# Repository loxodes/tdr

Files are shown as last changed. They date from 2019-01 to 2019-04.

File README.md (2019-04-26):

# tdr
Prototype time domain reflectometer/sampling oscilloscope.
90 gigasamples/second equivalent time sampling with an actual sampling rate of 5 kilosamples/second.

The input bandwidth is TBD, maybe 8 GHz?

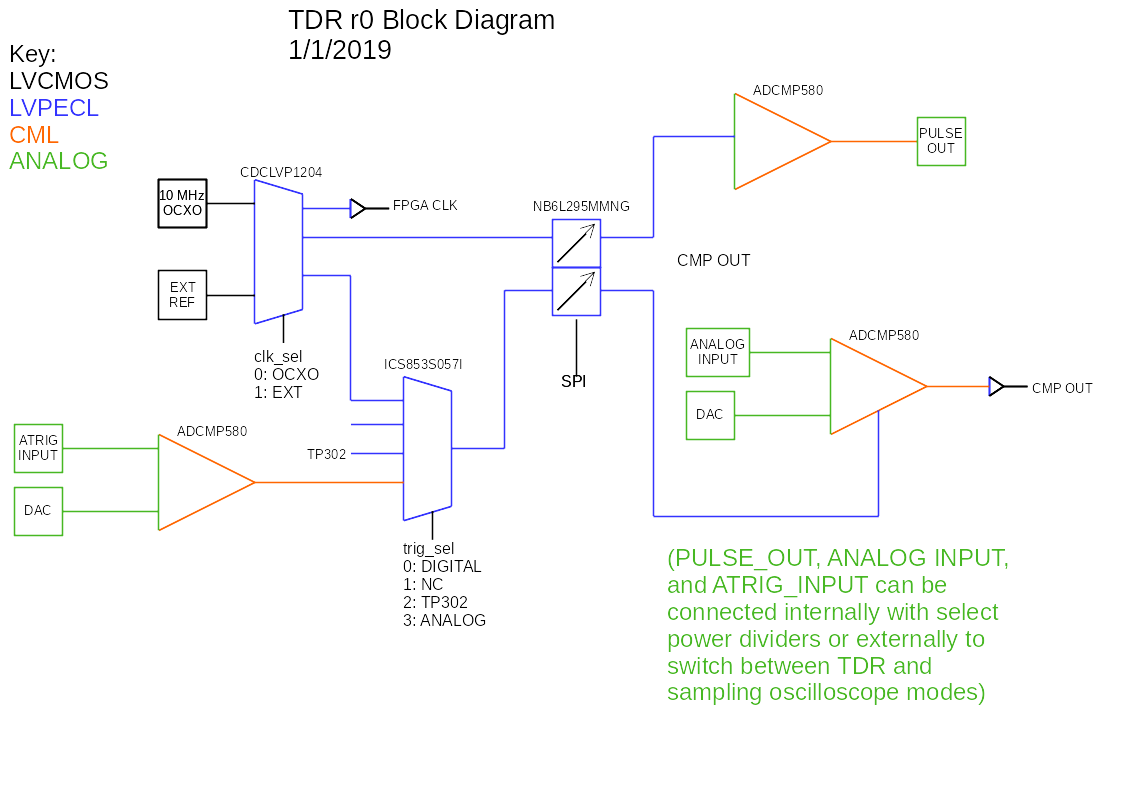
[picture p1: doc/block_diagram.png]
r0 block diagram

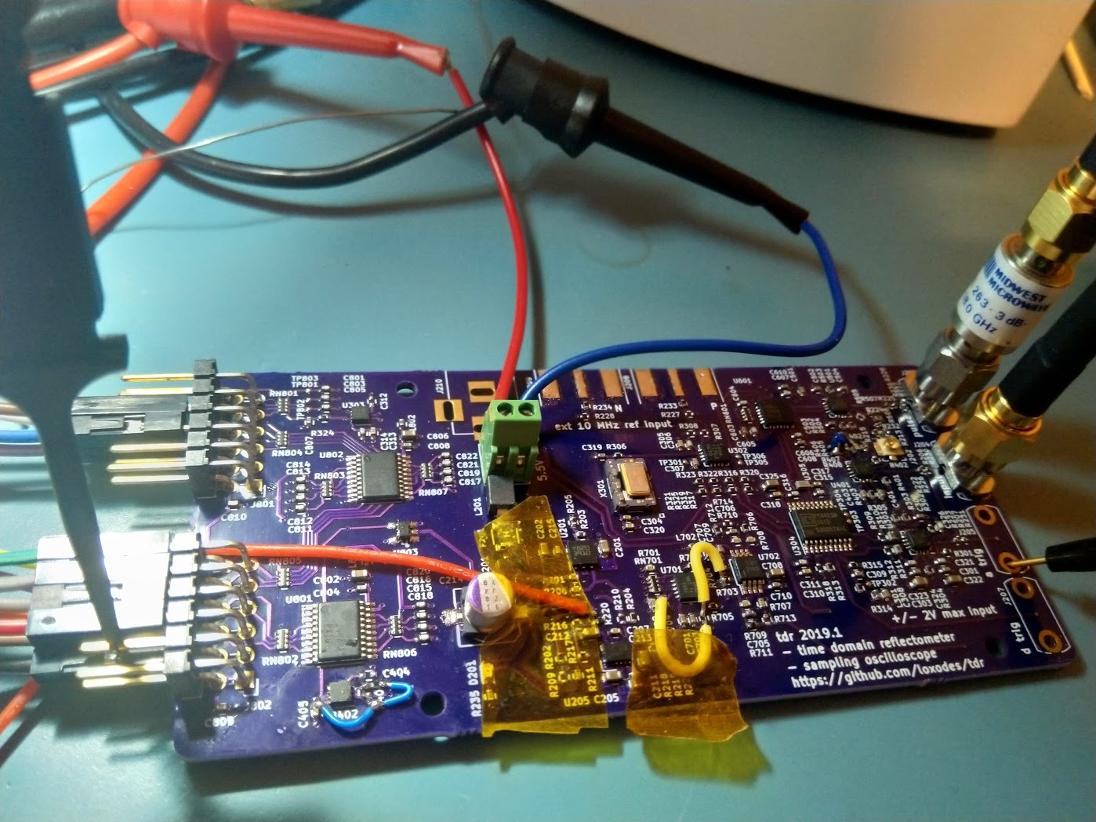
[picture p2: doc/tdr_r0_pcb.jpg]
r0 pcb


Following is sampling the falling edge of the TDR pulse, impedance of a BNC tee, and a 1.2 GHz sine wave with analog triggering.

r0 sweep
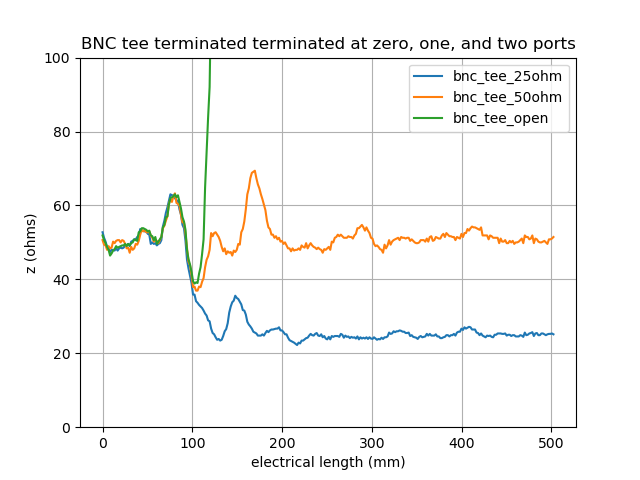
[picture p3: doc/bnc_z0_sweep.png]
r0 sweep

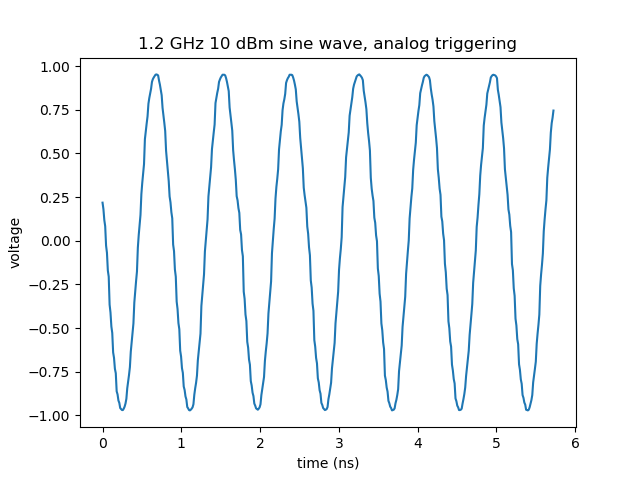
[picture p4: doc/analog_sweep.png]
r0 sweep


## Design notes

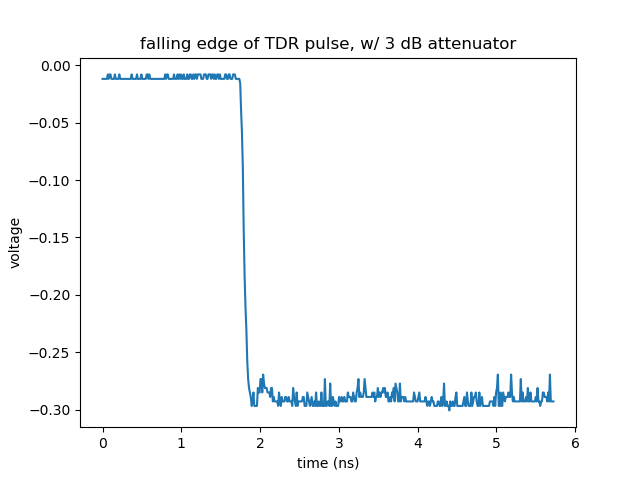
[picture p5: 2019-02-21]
doc/first_sweep.png

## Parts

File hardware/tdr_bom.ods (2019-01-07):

TDR R0 BOM
 | Item | Qty | Value | DigiKey PN | LibPart | Footprint | Reference(s)
 | 2 | 3 | 1 uF | 1276-1445-1-ND | Device:C_Small | Capacitors_SMD:C_0402 | C207, C701, C702
 | 3 | 1 | 10 uF | 490-10990-1-ND | Device:C_Small | Capacitors_SMD:C_0603 | C211
 | 4 | 12 | 4.7 uF | 1276-1784-1-ND | Device:C_Small | Capacitors_SMD:C_0603 | C212, C213, C201, C202, C205, C322, C324, C325, C406, C601, C707, C708,
 | 5 | 1 | 100 uF | P16482CT-ND | Device:CP1_Small | Capacitors_SMD:c_elec_6.3x5.8 | C214
 | 6 | 10 | 100 nF | 1292-1366-1-ND | Device:C_Small | Capacitors_SMD:C_0402 | C215, C305, C307, C310, C313, C317, C318, C320, C809, C810
 | 7 | 26 | 10 nF | 1276-1028-1-ND | Device:C_Small | Capacitors_SMD:C_0402 | C301, C302, C303, C304, C308, C309, C401, C402, C403, C405, C501, C502, C503, C504, C602, C603, C608, C610, C611, C613, C703, C704, C709, C710, C804, C808
 | 8 | 14 | 100 pF | 311-1024-1-ND | Device:C_Small | Capacitors_SMD:C_0402 | C306, C311, C314, C315, C316, C321, C323, C326, C604, C605, C606, C607, C609, C612
 | 9 | 2 | DNP | - | Device:C_Small | Capacitors_SMD:C_0402 | C312, C404
 | 10 | 4 | 10 pF | 1276-1139-1-ND | Device:C_Small | Capacitors_SMD:C_0402 | C319, C705, C706, C807
 | 11 | 4 | DNP | - | Device:C_Small | Capacitors_SMD:C_0603 | C802, C806
 | 12 | 15 | 33 pF | 311-1020-1-ND | Device:C_Small | Capacitors_SMD:C_0402 | C801, C803, C805, C811, C812, C813, C814, C815, C816, C817, C818, C819, C820, C821, C822
 | 13 | 1 | RED | 732-4978-1-ND | Device:LED | LEDs:LED_0603 | D201
 | 14 | 1 | Polyfuse_Small | F3371CT-ND | Device:Polyfuse_Small | Resistors_SMD:R_1210 | F201
 | 15 | 4 | MountingHole | - | Mechanical:MountingHole | Mounting_Holes:MountingHole_2-5mm | H201, H202, H203, H204
 | 16 | 1 | Conn_02x01 | A98333-ND | Connector_Generic:Conn_02x01 | Terminal_Blocks:TerminalBlock_Pheonix_MPT-2.54mm_2pol | J201
 | 17 | 1 | Conn_Coaxial | WM5587CT-ND | Connector:Conn_Coaxial | vna_footprints:734120110_ufl_umc | J202
 | 18 | 4 | Conn_Coaxial | SF2921-61345-2S-ND | Connector:Conn_Coaxial | vna_footprints:SF2921-61345 | J203, J204, J205, J207
 | 19 | 2 | Conn_Coaxial | WM5534-ND | Connector:Conn_Coaxial | vna_footprints:732511150_sma_thin_twopin | J208, J209
 | 20 | 1 | Barrel_Jack_Switch | - | Connector:Barrel_Jack_Switch | vna_footprints:BARREL_JACK | J210
 | 21 | 2 | Conn_02x06_Counter_Clockwise | A34346-06-ND | Connector_Generic:Conn_02x06_Counter_Clockwise | Pin_Headers:Pin_Header_Angled_2x06 | J801, J802
 | 22 | 1 | L_Small | 240-2435-1-ND | Device:L_Small | Resistors_SMD:R_1210 | L201
 | 23 | 5 | L_Small | 490-16507-1-ND | Device:L_Small | Resistors_SMD:R_0402 | L301, L701, L702, L801, L802
 | 24 | 1 | SI2369DS | SI2369DS-T1-GE3CT-ND | Device:Q_PMOS_GSD | TO_SOT_Packages_SMD:SOT-23 | Q201
 | 25 | 10 | 10k | RR05P10.0KDCT-ND | Device:R_Small | Resistors_SMD:R_0402 | R201, R208, R211, R235, R701, R707, R708, R709, R710, R712
 | 26 | 20 | JMP | 311-0.0JRCT-ND | Device:R_Small | Resistors_SMD:R_0402 | R202, R204, R227, R228, R233, R234, R301, R305, R324, R401, R405, R406, R407, R408, R502, R711, R220, R221, R306, R702
 | 30 | 2 | 1M | 311-1.00MLRCT-ND | Device:R_Small | Resistors_SMD:R_0402 | R216, R219
 | 31 | 2 | 332k | 311-332KLRCT-ND | Device:R_Small | Resistors_SMD:R_0402 | R217, R218
 | 33 | 7 | JMP | 311-0.0NCT-ND | Device:R_Small | Resistors_SMD:R_0201 | R222, R223, R229, R230, R231, R506, R507,
 | 34 | 3 | 50 | FC0402-50BWCT-ND | Device:R_Small | Resistors_SMD:R_0402 | R224, R309, R311
 | 35 | 8 | 1k | YAG1234CT-ND | Device:R_Small | Resistors_SMD:R_0402 | R303, R304, R313, R314, R315, R403, R503, R504
 | 36 | 4 | 84 | ERA-2AEB86R6X | Device:R_Small | Resistors_SMD:R_0402 | R316, R317, R322, R323
 | 37 | 4 | 125 | YAG4336CT-ND | Device:R_Small | Resistors_SMD:R_0402 | R319, R320, R321, R325
 | 38 | 1 | 100 | 311-2216-1-ND | Device:R_Small | Resistors_SMD:R_0402 | R404
 | 39 | 2 | 68 | 311-68UCT-ND | Device:R_Small | Resistors_SMD:R_0402 | R601, R602
 | 40 | 4 | 13k | YAG3274CT-ND | Device:R_Small | Resistors_SMD:R_0402 | R703, R704, R705, R706
 | 41 | 9 | 22 | Y7220CT-ND | Device:R_Pack04 | Resistors_SMD:R_Array_Convex_4x0402 | RN601, RN701, RN801, RN802, RN803, RN804, RN805, RN806, RN807
 | 42 | 1 | LD39100PU33R | 497-11013-1-ND | ld39100:LD39100 | Housings_DFN_QFN:DFN-6-1EP_3x3mm_Pitch0.95mm | U201
 | 43 | 1 | LM27762 | 296-47331-1-ND | lm27762:LM27762 | vna_footprints:WSON-12-1EP_3x2mm_Pitch0.5mm | U205
 | 45 | 1 | CDCLVP1204 | 296-41231-1-ND | tdr-rescue:CDCLVP1204-synth_lib-tdr-rescue | Housings_DFN_QFN:UQFN-16-1EP_3x3mm_Pitch0.5mm | U302
 | 47 | 1 | ICS853S057I | 800-2923-5-ND | tdr-rescue:ICS853S057I-tdr | Housings_SSOP:TSSOP-20_4.4x6.5mm_Pitch0.65mm | U304
 | 48 | 1 | X0060L5050AHF | Mouser X0060L5050AHF | synth_lib:X0060L5050AHF | synth_footprints:X0060L5050AHF | U305
 | 49 | 3 | ADCMP580 | ADCMP580BCPZ-WP-ND | tdr-rescue:ADCMP580-synth_lib-tdr-rescue | Housings_DFN_QFN:QFN-16-1EP_3x3mm_Pitch0.5mm | U301, U401, U501
 | 50 | 2 | SY89321L | 576-2954-1-ND | tdr-rescue:SY89321L-synth_lib-tdr-rescue | vna_footprints:DFN-8-1EP_2x2mm_Pitch0.5mm | U402, U303
 | 51 | 1 | NB6L295MMNG | NB6L295MMNGOS-ND | tdr-rescue:NB6L295MMNG-synth_lib-tdr-rescue | Housings_DFN_QFN:QFN-24-1EP_4x4mm_Pitch0.5mm | U601
 | 52 | 1 | DAC7563SDSCR | 296-29025-1-ND | synth_lib:DAC7563SDSCR | Housings_DFN_QFN:DFN-10-1EP_3x3mm_Pitch0.5mm | U701
 | 53 | 1 | OPA2140 | 296-46321-1-ND | Device:Opamp_Dual_Generic | Housings_SSOP:MSOP-8_3x3mm_Pitch0.65mm | U702
 | 54 | 2 | 74HC244 | MC74HC244ADTR2G | 74xx:74HC244 | Housings_SSOP:TSSOP-20_4.4x6.5mm_Pitch0.65mm | U801, U802
 | 55 | 1 | 74xx1G14 | 1727-3262-1-ND | 74xx1g14:74xx1G14 | TO_SOT_Packages_SMD:SOT-23-5 | U803
 | 56 | 1 | DV75D-010.0M | CW743CT-ND | tdr-rescue:DV75D_TCXO-synth_lib-tdr-rescue | vna_footprints:DV75D | X301

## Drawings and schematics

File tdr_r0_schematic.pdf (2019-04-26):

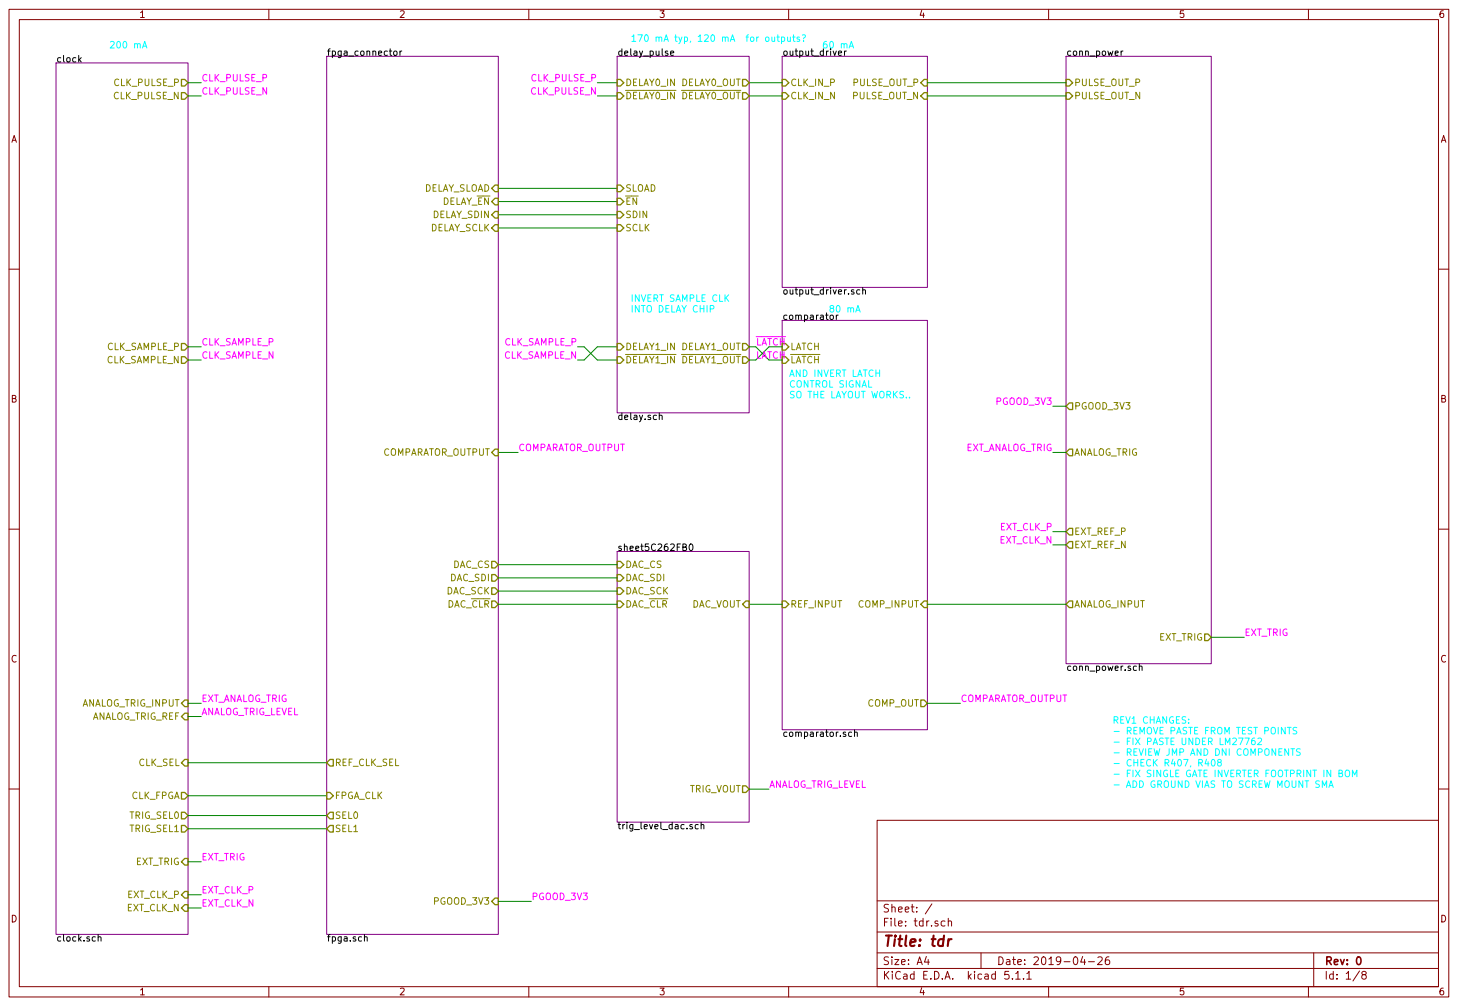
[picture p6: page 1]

CONTROL SIGNAL SO THE LAYOUT WORKS.. LATCH
LATCH

REV1 CHANGES: - REMOVE PASTE FROM TEST POINTS

- FIX PASTE UNDER LM27762
- REVIEW JMP AND DNI COMPONENTS
- CHECK R407, R408
- FIX SINGLE GATE INVERTER FOOTPRINT IN BOM
- ADD GROUND VIAS TO SCREW MOUNT SMA

Id: 1/8 Title: tdr File: tdr.sch Sheet: /

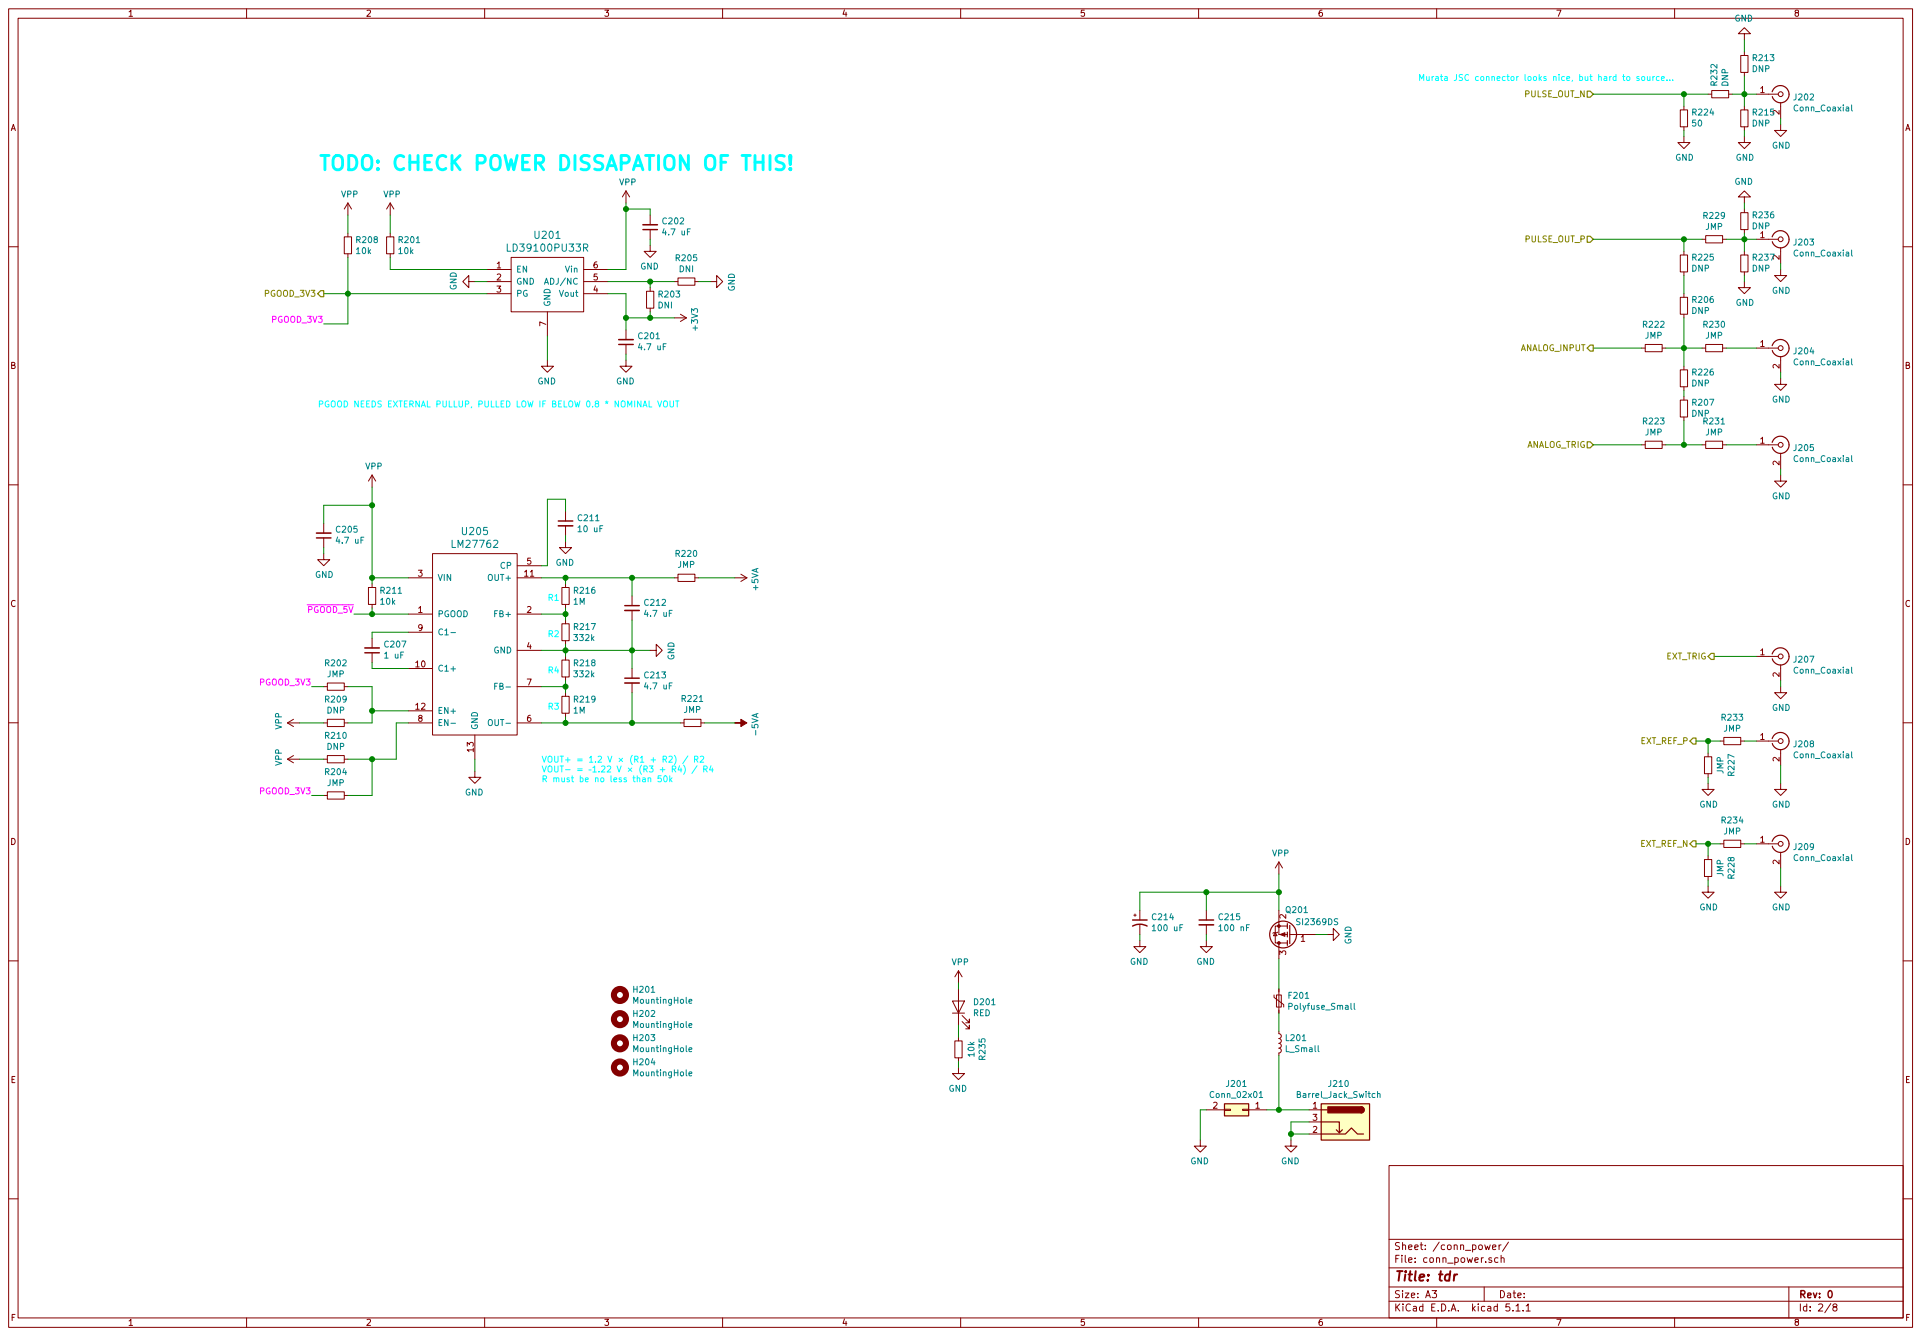
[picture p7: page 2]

Murata JSC connector looks nice, but hard to source...

PGOOD_3V3 PGOOD NEEDS EXTERNAL PULLUP, PULLED LOW IF BELOW 0.8 * NOMINAL VOUT TODO: CHECK POWER DISSAPATION OF THIS!
10k VPP
PGOOD_3V3 R204

VOUT- = 1.22 V × (R3 + R4) / R4 R must be no less than 50k R1 R2 R4 R3

H201 MountingHole H202 MountingHole H203 MountingHole H204 MountingHole

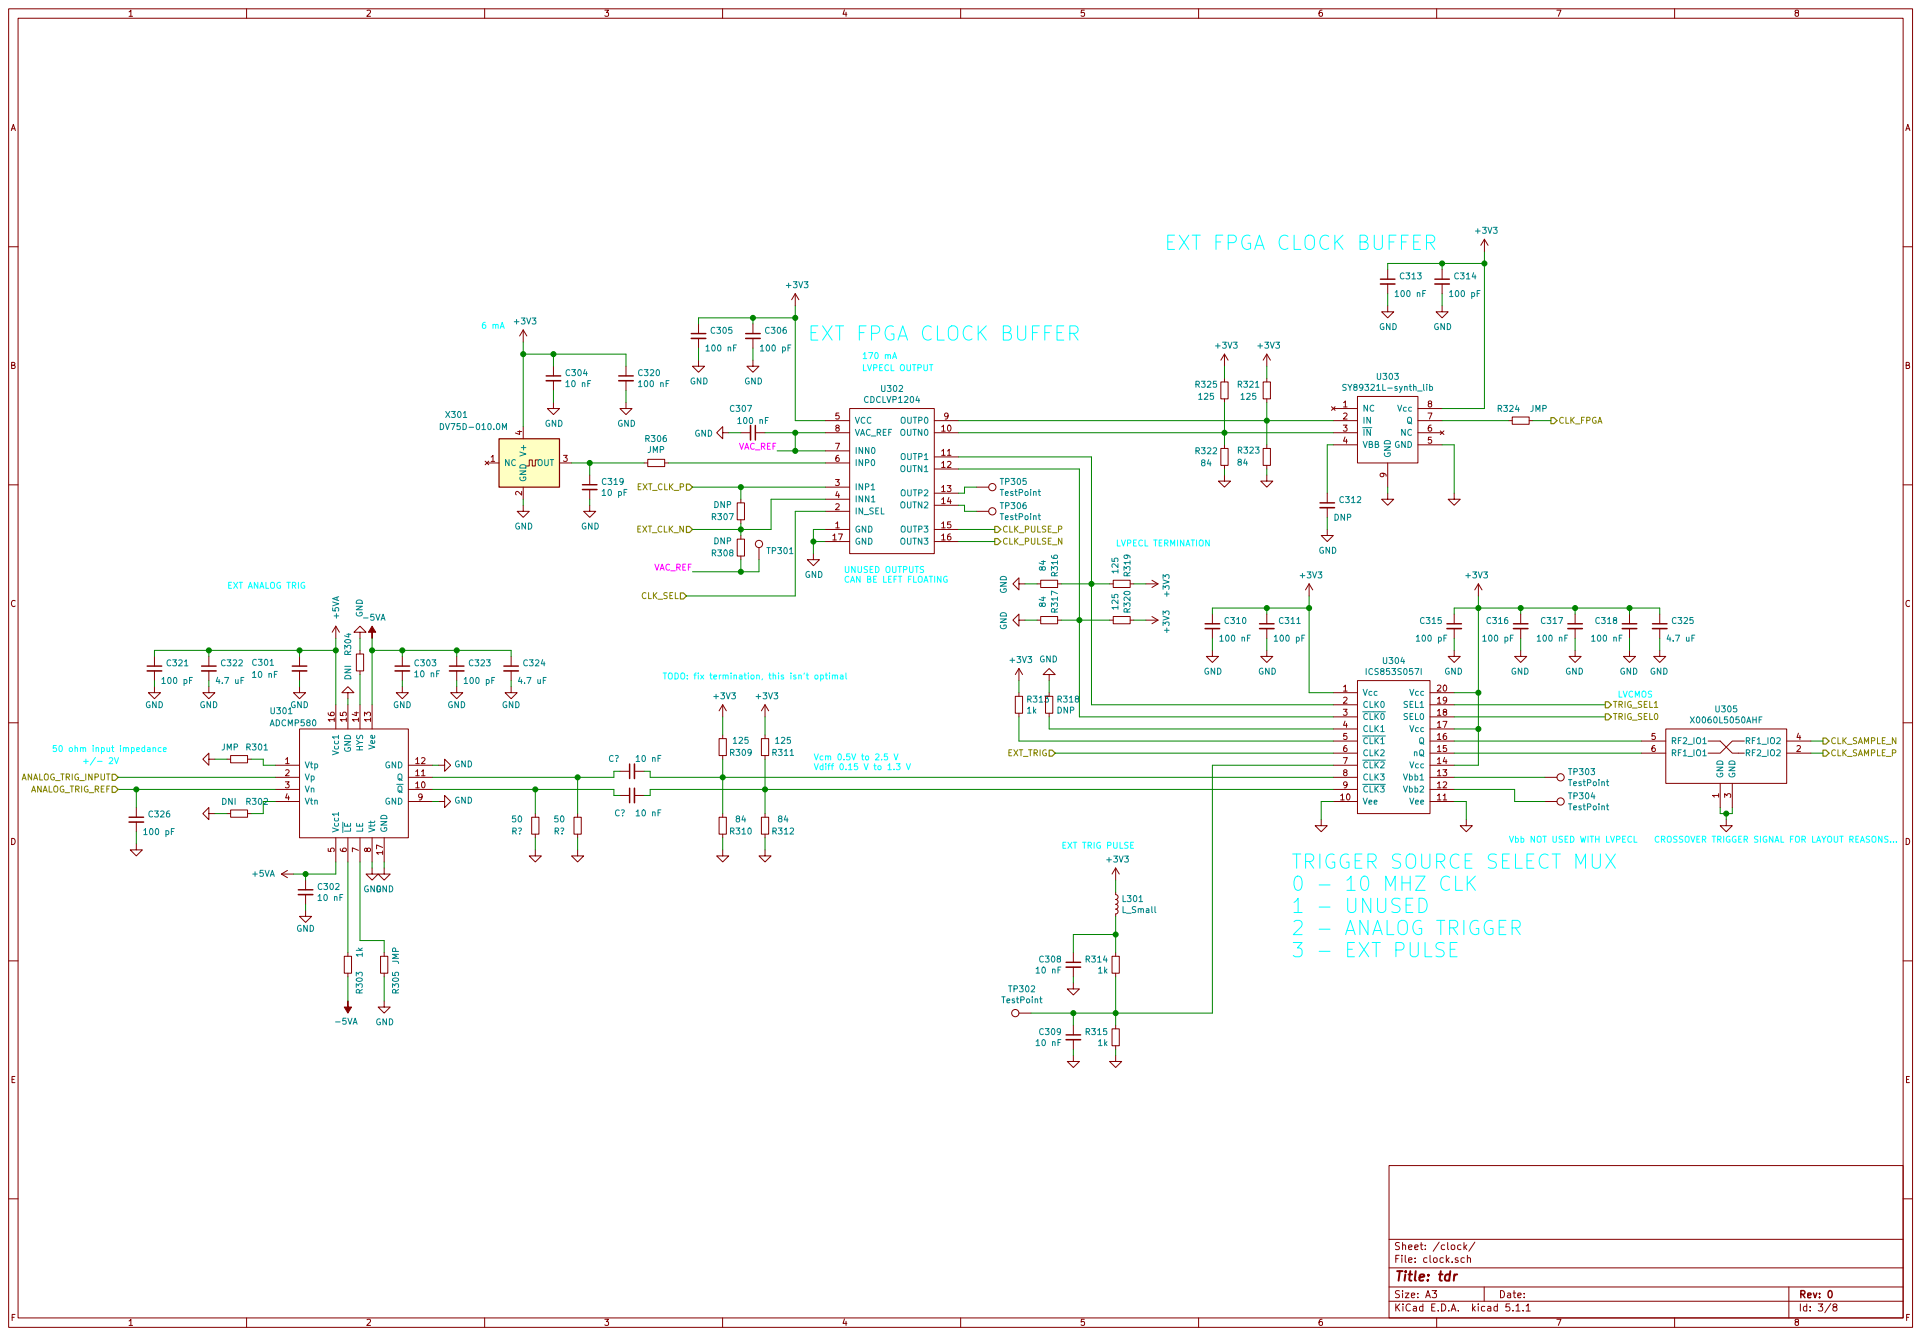
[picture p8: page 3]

EXT FPGA CLOCK BUFFER

TP303 TestPoint TP304 TestPoint Vbb NOT USED WITH LVPECL C319
10 pF GND

7 Vtt 8 GND 9 U301 ADCMP580 +5VA -5VA GNDGND GND GND

4.7 uF GND TRIGGER SOURCE SELECT MUX
1k EXT_TRIG

TODO: fix termination, this isn't optimal

CROSSOVER TRIGGER SIGNAL FOR LAYOUT REASONS... GND

Id: 3/8 Title: tdr File: clock.sch Sheet: /clock/

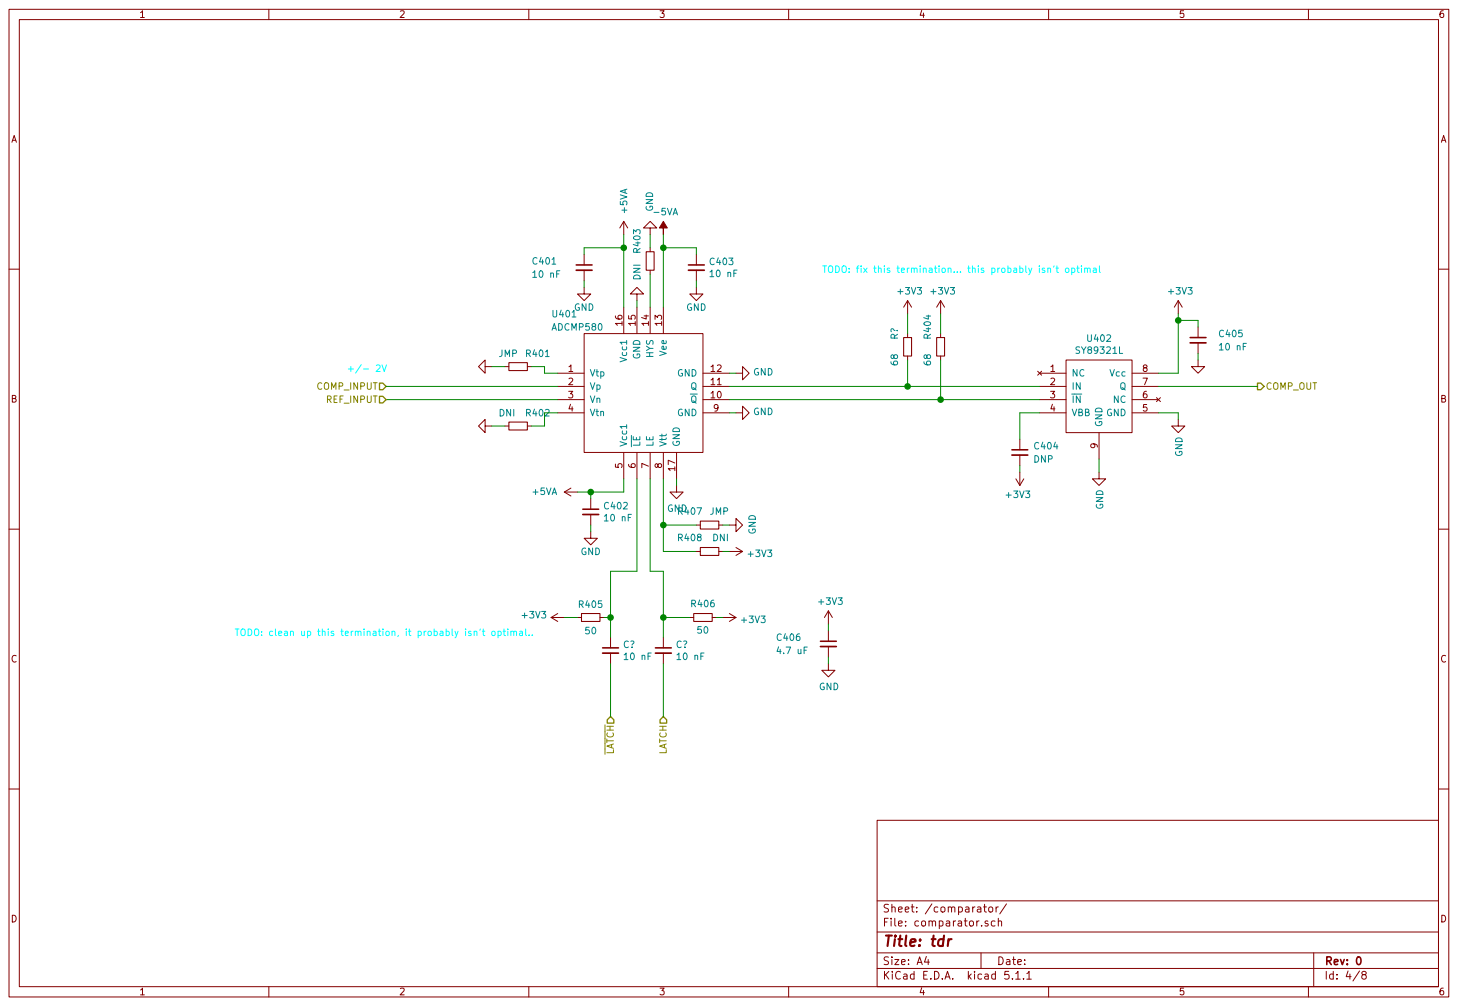
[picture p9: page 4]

7 Vtt 8 GND 9 U401 ADCMP580 +5VA -5VA GND GND GND GND

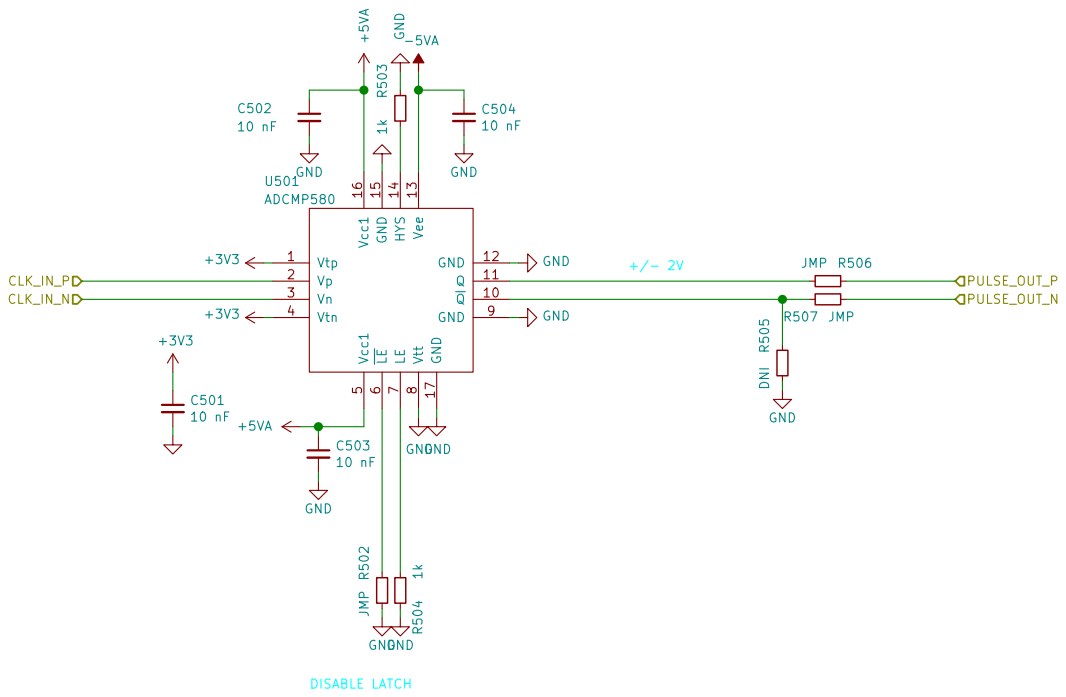
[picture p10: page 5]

7 Vtt 8 GND 9 U501 ADCMP580 +5VA -5VA GNDGND GND GND

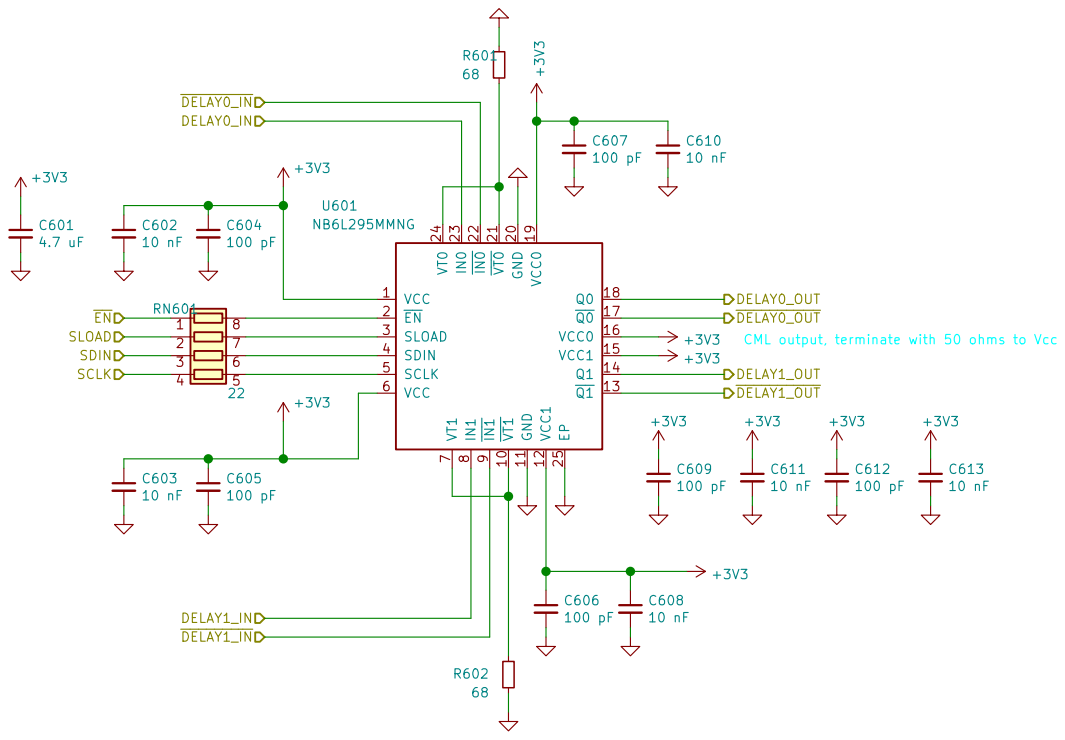
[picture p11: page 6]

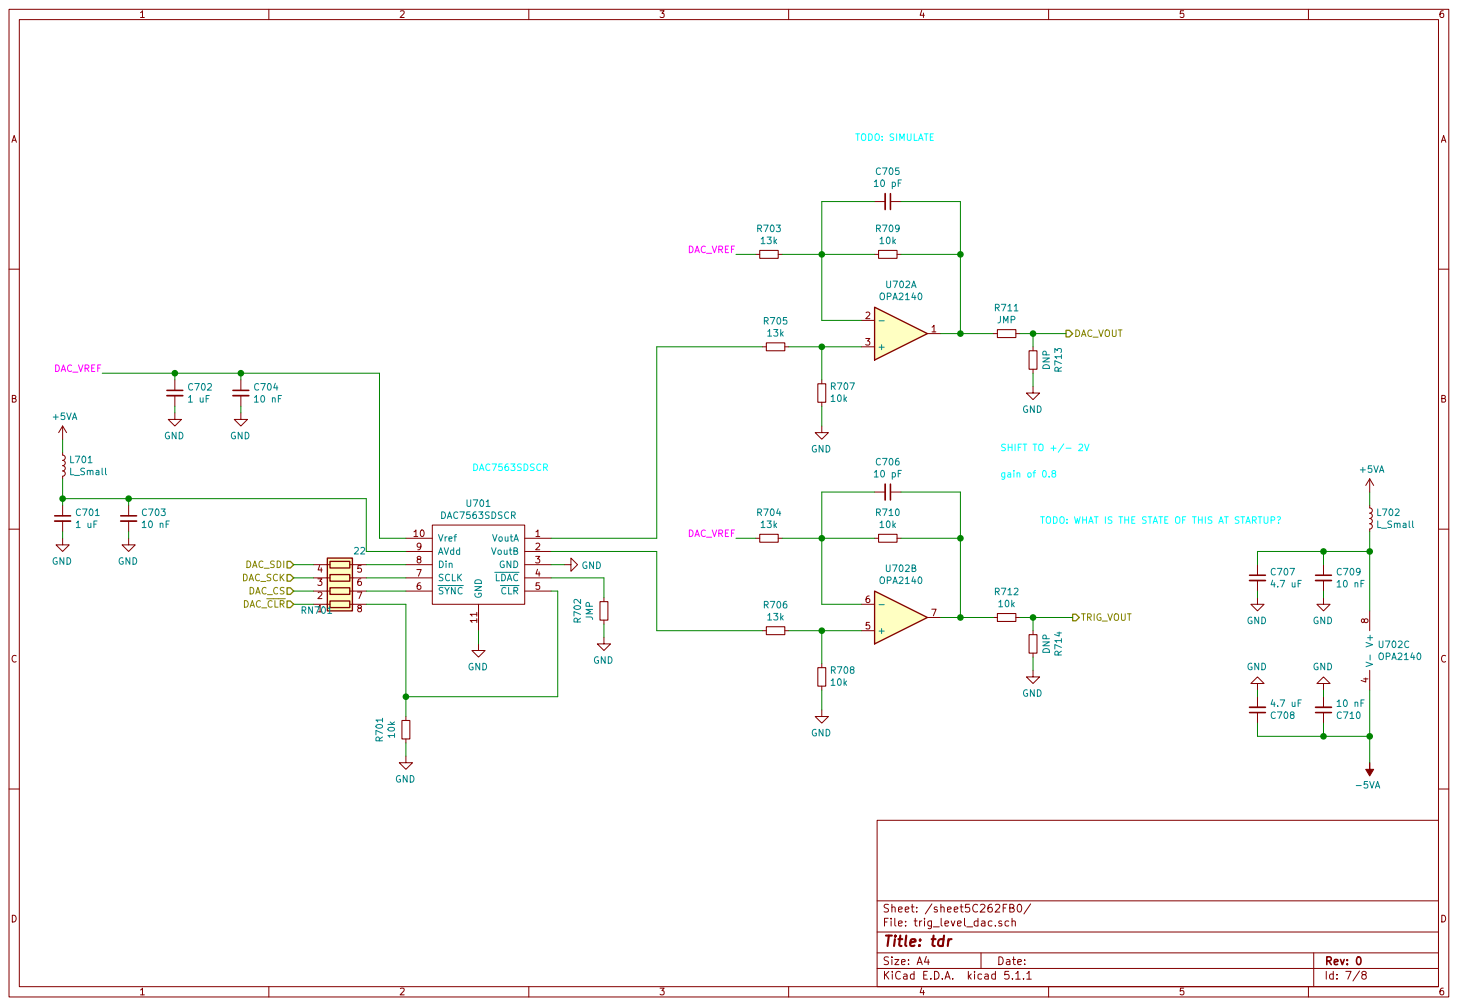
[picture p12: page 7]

TODO: WHAT IS THE STATE OF THIS AT STARTUP?

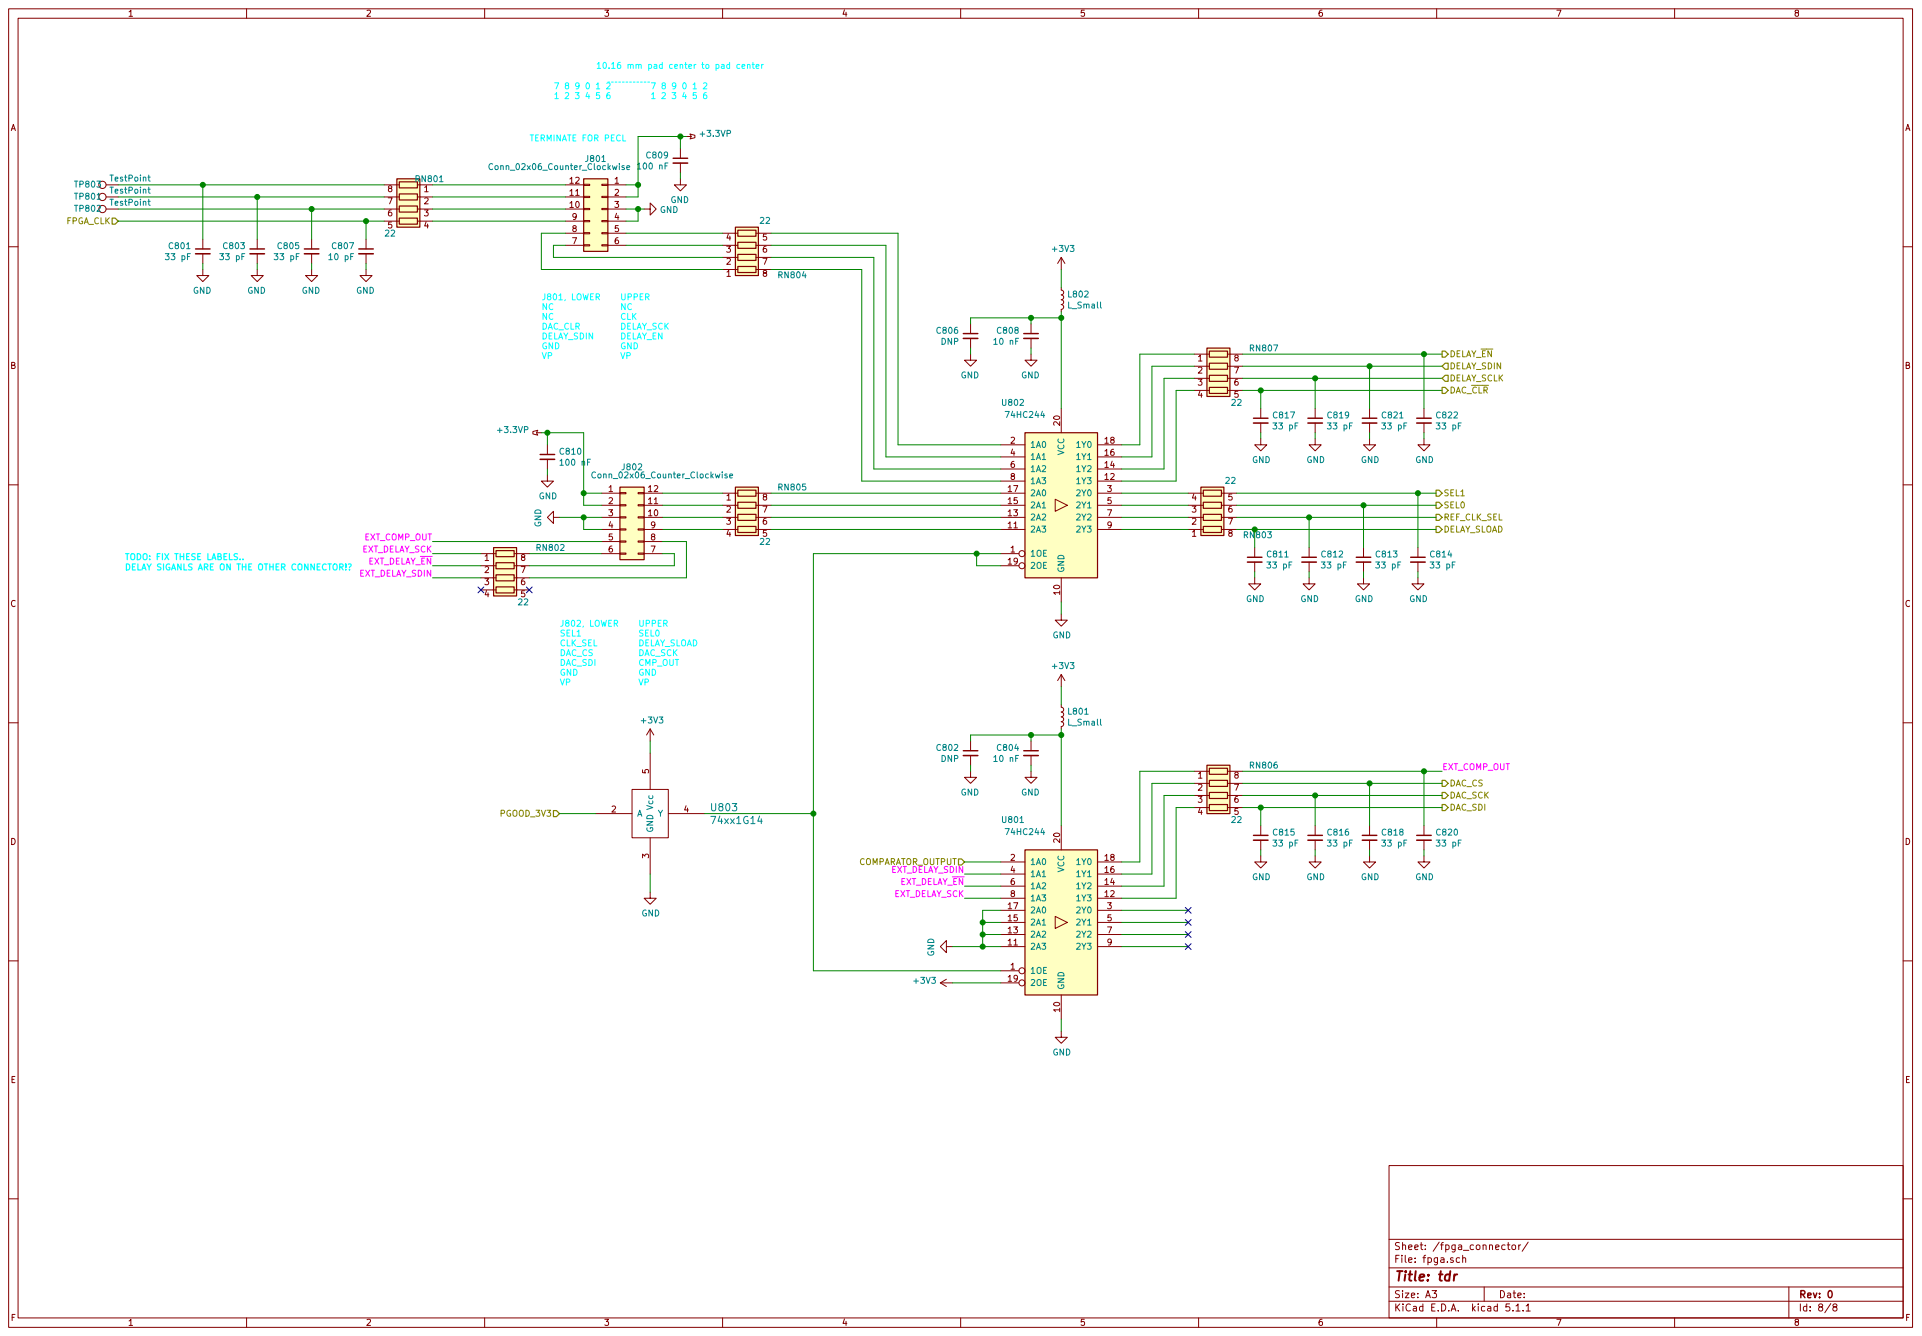
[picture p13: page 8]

TODO: FIX THESE LABELS.. DELAY SIGANLS ARE ON THE OTHER CONNECTOR!?

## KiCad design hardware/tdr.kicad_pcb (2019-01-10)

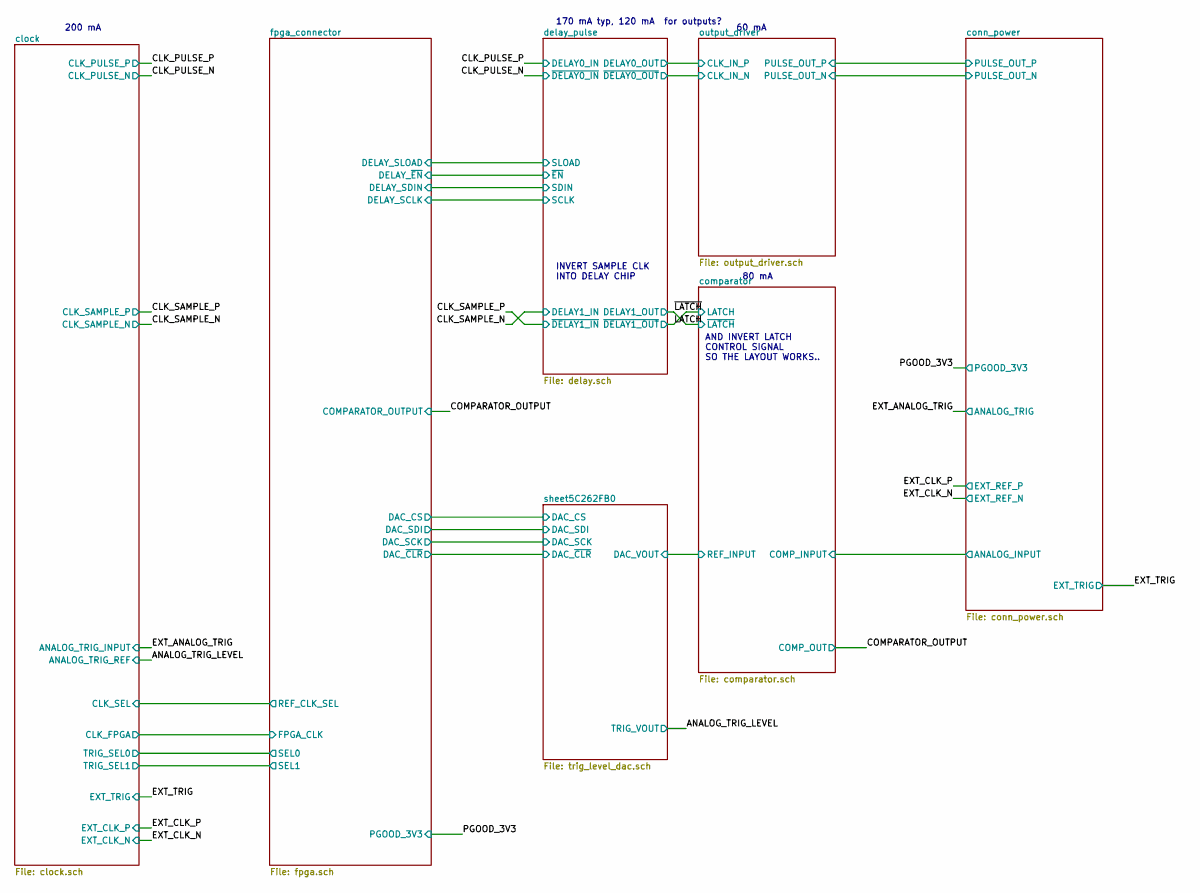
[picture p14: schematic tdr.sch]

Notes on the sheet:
200 mA
170 mA typ, 120 mA for outputs?
60 mA
80 mA
INVERT SAMPLE CLK INTO DELAY CHIP
AND INVERT LATCH CONTROL SIGNAL SO THE LAYOUT WORKS..

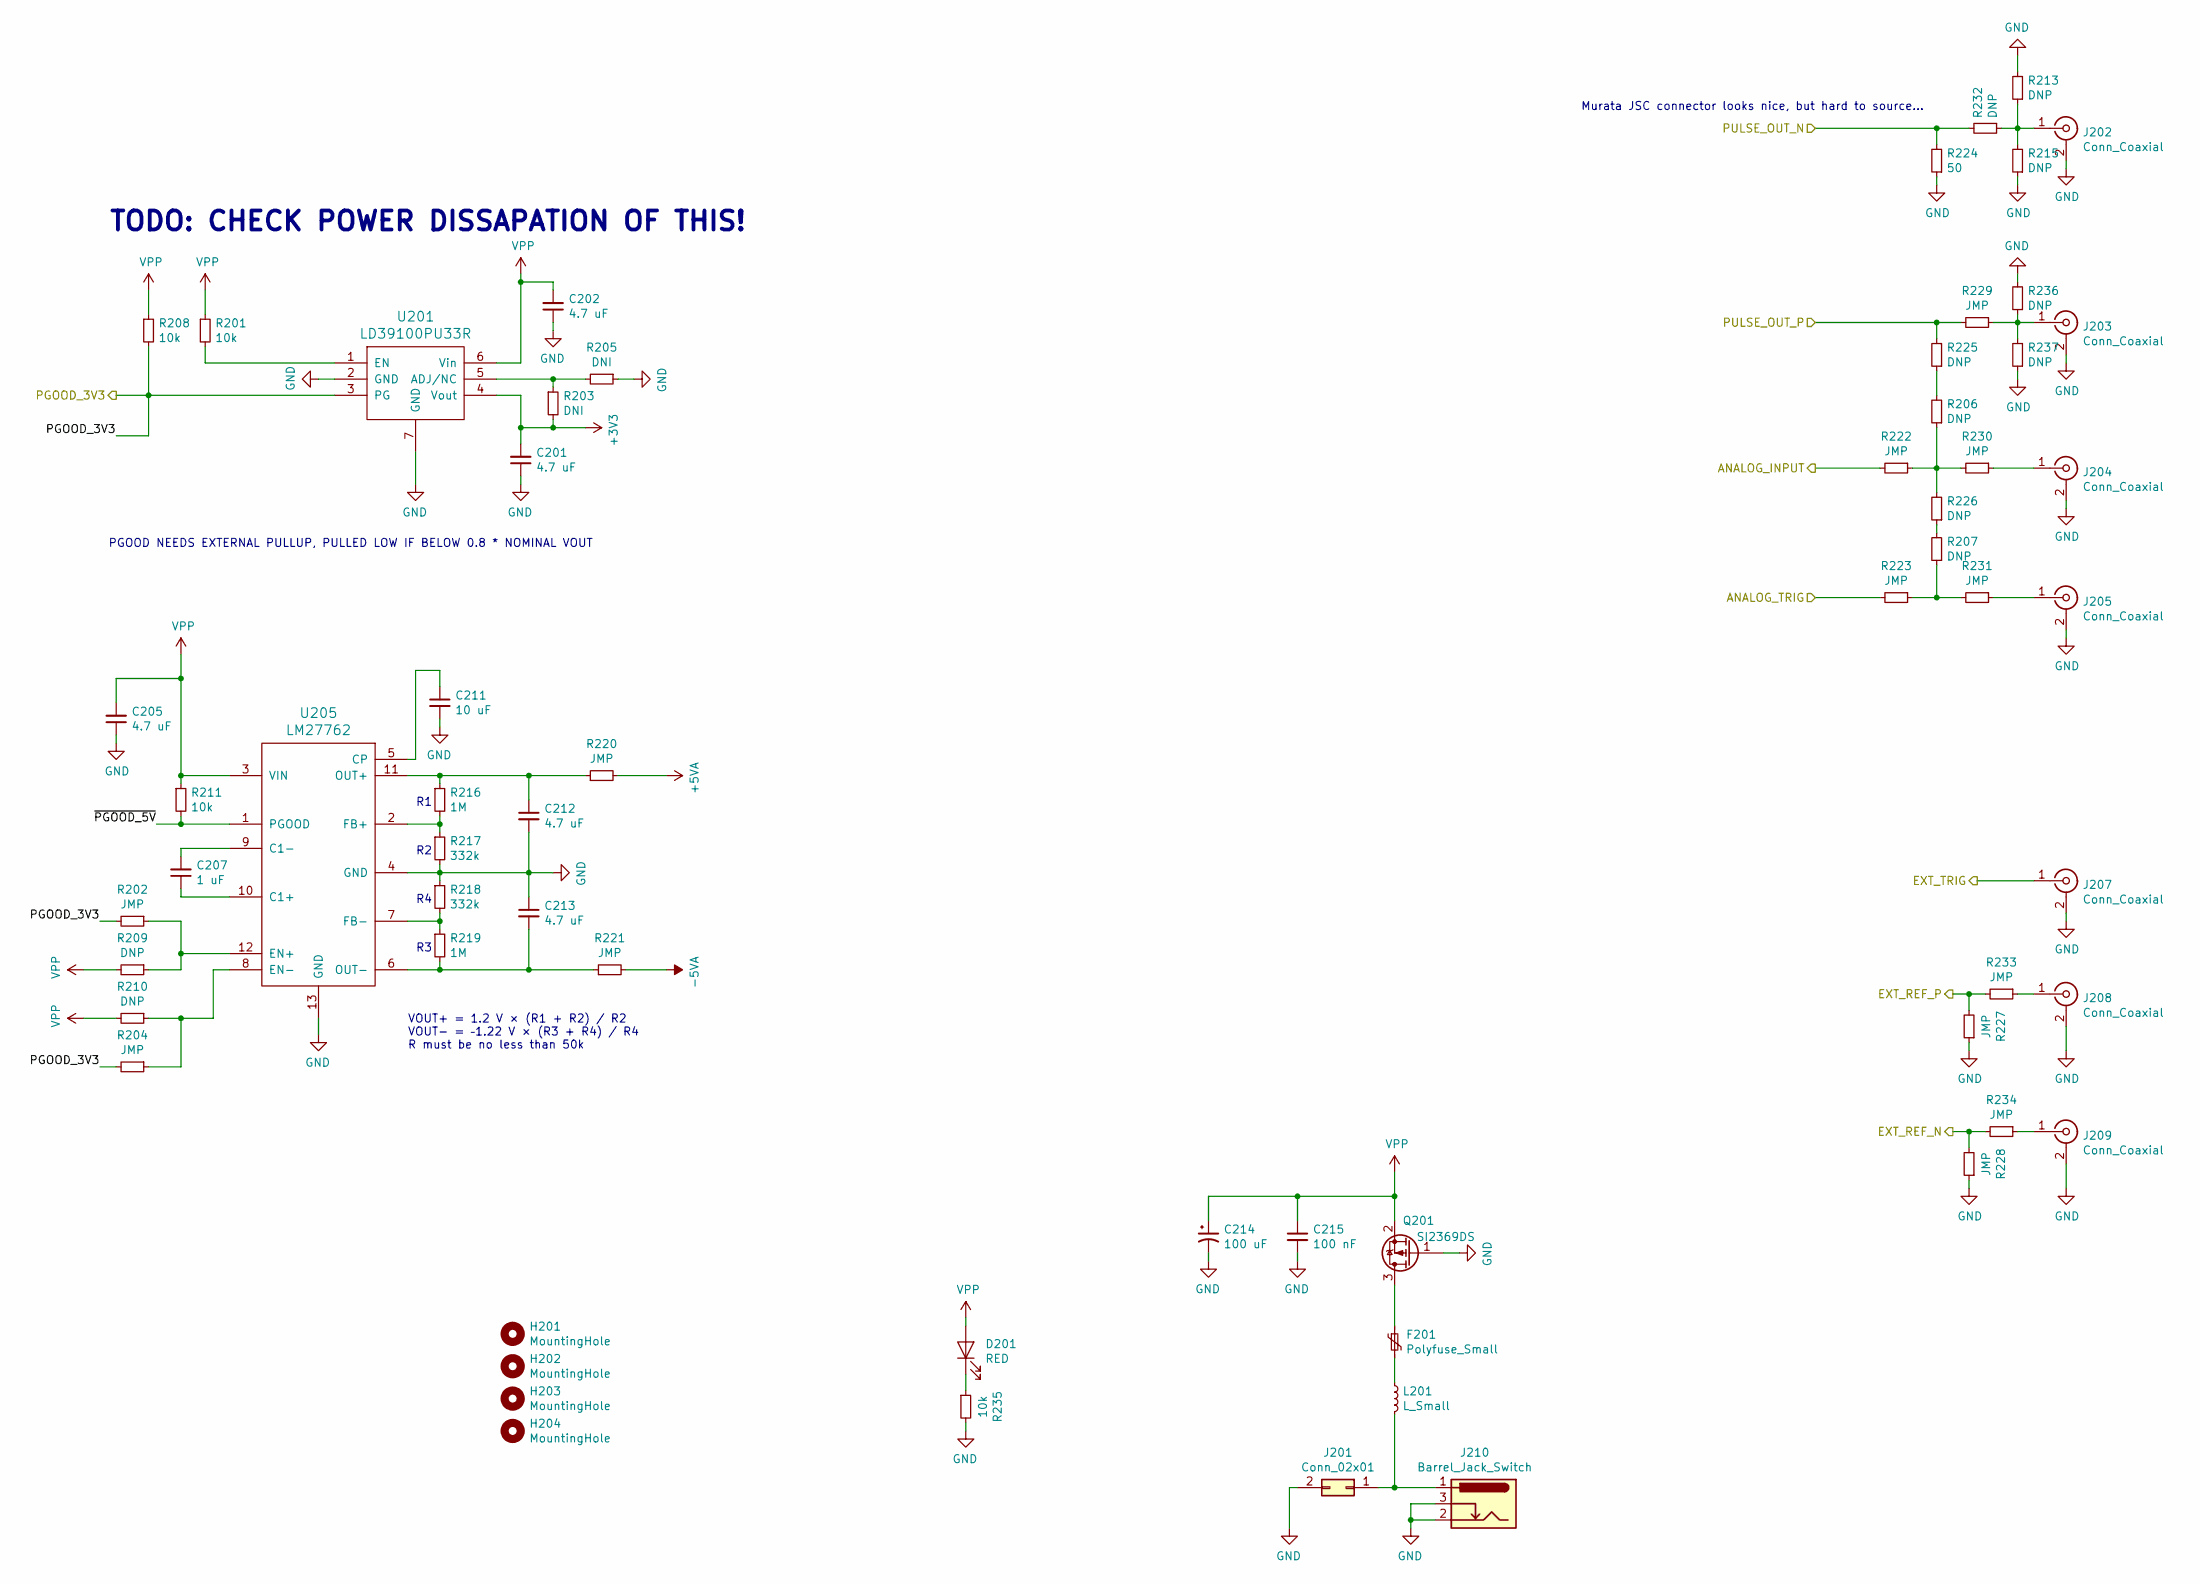
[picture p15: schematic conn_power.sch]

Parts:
C201, C202, C205, C212, C213: 4.7 uF; C_0603
C207: 1 uF; C_0402
C211: 10 uF; C_0603
C214: 100 uF; c_elec_6.3x5.8
C215: 100 nF; C_0402
D201: RED; LED_0603
F201: Polyfuse_Small; R_1210
H201, H202, H203, H204: MountingHole; MountingHole_2-5mm
J201: Conn_02x01; TerminalBlock_Pheonix_MPT-2.54mm_2pol
J202: Conn_Coaxial; 734120110_ufl_umc
J203, J204, J205, J207: Conn_Coaxial; SF2921-61345
J208, J209: Conn_Coaxial; 732511150_sma_thin_twopin
J210: Barrel_Jack_Switch; BARREL_JACK
L201: L_Small; R_1210
Q201: SI2369DS; SOT-23
R201, R208, R211, R235: 10k; R_0402
R202, R204, R220, R221, R227, R228, R233, R234: JMP; R_0402
R203, R205: DNI; R_0402
R206, R207, R225, R226, R232: DNP; R_0201
R209, R210, R213, R215, R236, R237: DNP; R_0402
R216, R219: 1M; R_0402
R217, R218: 332k; R_0402
R222, R223, R229, R230, R231: JMP; R_0201
R224: 50; R_0402
U201: LD39100PU33R; DFN-6-1EP_3x3mm_Pitch0.95mm
U205: LM27762; WSON-12-1EP_3x2mm_Pitch0.5mm

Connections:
+3V3: C201.2, R203.2, U201.4 (Vout); also elsewhere on the board
+5VA: R220.2; also elsewhere on the board
-5VA: R221.2; also elsewhere on the board
/EXT_ANALOG_TRIG: R223.2; also elsewhere on the board
/EXT_CLK_N: R228.2, R234.2; also elsewhere on the board
/EXT_CLK_P: R227.2, R233.2; also elsewhere on the board
/EXT_TRIG: J207.1 (In); also elsewhere on the board
/PGOOD_3V3: R202.2, R204.2, R208.2, U201.3 (PG); also elsewhere on the board
/conn_power/ANALOG_INPUT: R222.2; also elsewhere on the board
/conn_power/PULSE_OUT_N: R224.2, R232.2; also elsewhere on the board
/conn_power/PULSE_OUT_P: R225.2, R229.2; also elsewhere on the board
/conn_power/~PGOOD_5V: R211.2, U205.1 (PGOOD)
GND: C201.1, C202.1, C205.1, C211.2, C212.2, C213.1, C214.2, C215.2, J201.2, J202.2 (Ext), J203.2 (Ext), J204.2 (Ext), J205.2 (Ext), J207.2 (Ext), J208.2 (Ext), J209.2 (Ext), J210.2, J210.3, Q201.1 (G), R205.1, R213.2, R215.1, R217.2, R218.1, R224.1, R227.1, R228.1, R235.2, R236.2, R237.1, U201.2 (GND), U201.7 (GND), U205.4 (GND), U205.13 (GND); also elsewhere on the board
unnamed: C207.1, U205.10 (C1+)
unnamed: C207.2, U205.9 (C1-)
unnamed: C211.1, U205.5 (CP)
unnamed: C212.1, R216.1, R220.1, U205.11 (OUT+)
unnamed: C213.2, R219.2, R221.1, U205.6 (OUT-)
unnamed: D201.1 (K), R235.1
unnamed: F201.1, Q201.3 (D)
unnamed: F201.2, L201.1
unnamed: J201.1, J210.1, L201.2
unnamed: J202.1 (In), R213.1, R215.2, R232.1
unnamed: J203.1 (In), R229.1, R236.1, R237.2
unnamed: J204.1 (In), R230.1
unnamed: J205.1 (In), R231.1
unnamed: J208.1 (In), R233.1
unnamed: J209.1 (In), R234.1
unnamed: R201.2, U201.1 (EN)
unnamed: R202.1, R209.1, U205.12 (EN+)
unnamed: R203.1, R205.2, U201.5 (ADJ/NC)
unnamed: R204.1, R210.1, U205.8 (EN-)
unnamed: R206.1, R222.1, R226.2, R230.2
unnamed: R206.2, R225.1
unnamed: R207.1, R223.1, R231.2
unnamed: R207.2, R226.1
unnamed: R216.2, R217.1, U205.2 (FB+)
unnamed: R218.2, R219.1, U205.7 (FB-)
VPP: C202.2, C205.2, C214.1, C215.1, D201.2 (A), Q201.2 (S), R201.1, R208.1, R209.2, R210.2, R211.1, U201.6 (Vin), U205.3 (VIN)

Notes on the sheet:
PGOOD NEEDS EXTERNAL PULLUP, PULLED LOW IF BELOW 0.8 * NOMINAL VOUT
TODO: CHECK POWER DISSAPATION OF THIS!
Murata JSC connector looks nice, but hard to source...
VOUT+ = 1.2 V × (R1 + R2) / R2 VOUT- = –1.22 V × (R3 + R4) / R4 R must be no less than 50k

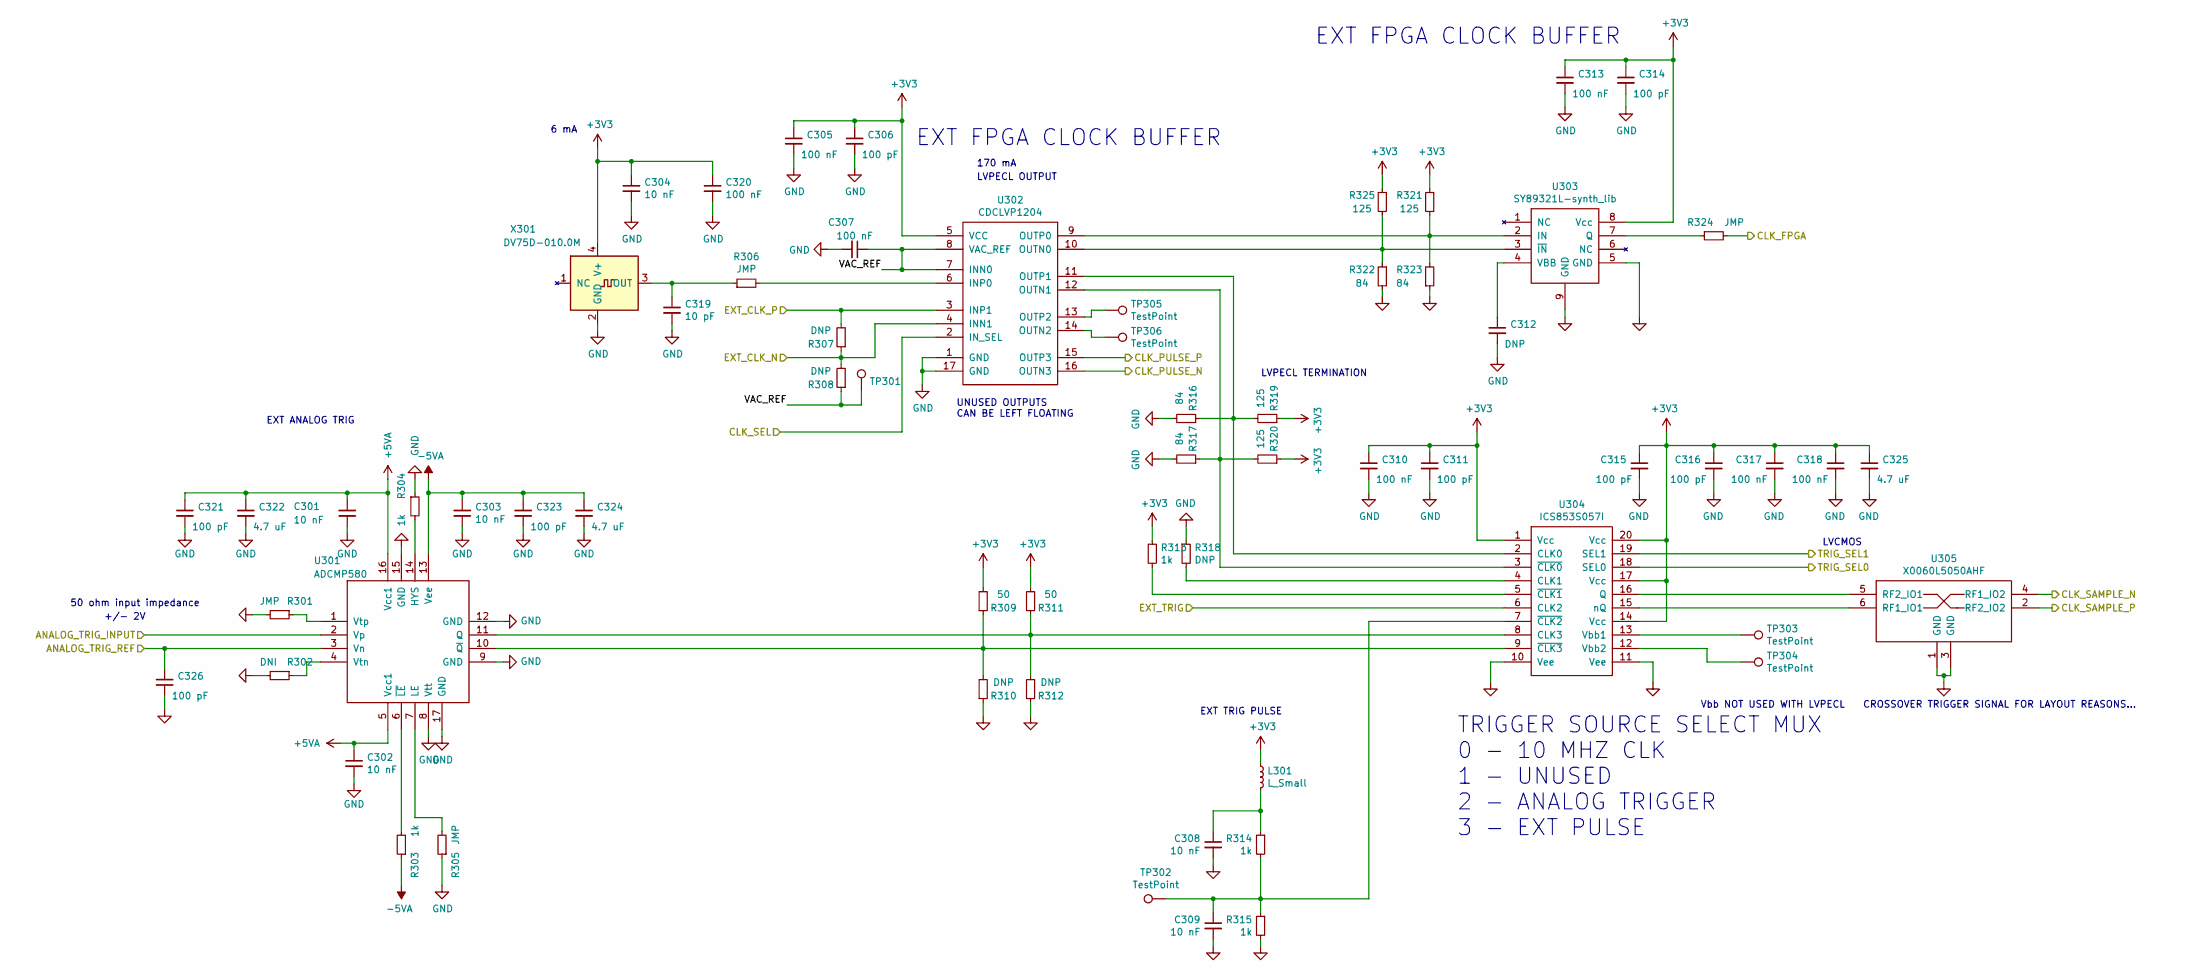
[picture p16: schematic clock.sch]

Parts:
C301, C302, C303, C304, C308, C309: 10 nF; C_0402
C305, C307, C310, C313, C317, C318, C320: 100 nF; C_0402
C306, C311, C314, C315, C316, C321, C323, C326: 100 pF; C_0402
C312: DNP; C_0402
C319: 10 pF; C_0402
C322, C324, C325: 4.7 uF; C_0603
L301: L_Small; R_0402
R301, R305, R306, R324: JMP; R_0402
R302: DNI; R_0402
R303, R304, R313, R314, R315: 1k; R_0402
R307, R308, R310, R312, R318: DNP; R_0402
R309, R311: 50; R_0402
R316, R317, R322, R323: 84; R_0402
R319, R320, R321, R325: 125; R_0402
TP301, TP302, TP303, TP304, TP305, TP306: TestPoint; TP07R
U301: ADCMP580; UQFN-16-1EP_3x3mm_Pitch0.5mm
U302: CDCLVP1204; UQFN-16-1EP_3x3mm_Pitch0.5mm
U303: SY89321L-synth_lib; DFN-8-1EP_2x2mm_Pitch0.5mm
U304: ICS853S057I; TSSOP-20_4.4x6.5mm_Pitch0.65mm
U305: X0060L5050AHF
X301: DV75D-010.0M; DV75D

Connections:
+3V3: C304.1, C305.1, C306.1, C310.1, C311.1, C313.1, C314.1, C315.1, C316.1, C317.1, C318.1, C320.1, C325.1, L301.1, R309.2, R311.2, R313.1, R319.1, R320.1, R321.1, R325.1, U302.5 (VCC), U303.8 (Vcc), U304.1 (Vcc), U304.14 (Vcc), U304.17 (Vcc), U304.20 (Vcc), X301.4 (V+); also elsewhere on the board
+5VA: C301.1, C302.1, C321.1, C322.1, U301.5 (Vcc1), U301.16 (Vcc1); also elsewhere on the board
-5VA: C303.1, C323.1, C324.1, R303.1, U301.13 (Vee); also elsewhere on the board
/ANALOG_TRIG_LEVEL: C326.1, U301.3 (Vn); also elsewhere on the board
/CLK_PULSE_N: U302.16 (OUTN3); also elsewhere on the board
/CLK_PULSE_P: U302.15 (OUTP3); also elsewhere on the board
/CLK_SAMPLE_N: U305.4 (RF1_IO2); also elsewhere on the board
/CLK_SAMPLE_P: U305.2 (RF2_IO2); also elsewhere on the board
/EXT_ANALOG_TRIG: U301.2 (Vp); also elsewhere on the board
/EXT_CLK_N: R307.1, R308.2, U302.4 (INN1); also elsewhere on the board
/EXT_CLK_P: R307.2, U302.3 (INP1); also elsewhere on the board
/EXT_TRIG: U304.6 (CLK2); also elsewhere on the board
/clock/CLK_FPGA: R324.2; also elsewhere on the board
/clock/CLK_SEL: U302.2 (IN_SEL); also elsewhere on the board
/clock/VAC_REF: C307.1, R308.1, TP301.1, U302.7 (INN0), U302.8 (VAC_REF)
/fpga_connector/SEL0: U304.18 (SEL0); also elsewhere on the board
/fpga_connector/SEL1: U304.19 (SEL1); also elsewhere on the board
GND: C301.2, C302.2, C303.2, C304.2, C305.2, C306.2, C307.2, C308.2, C309.2, C310.2, C311.2, C312.2, C313.2, C314.2, C315.2, C316.2, C317.2, C318.2, C319.2, C320.2, C321.2, C322.2, C323.2, C324.2, C325.2, C326.2, R301.2, R302.2, R304.1, R305.1, R310.1, R312.1, R315.2, R316.2, R317.2, R318.1, R322.2, R323.1, U301.8 (Vtt), U301.9 (GND), U301.12 (GND), U301.15 (GND), U301.17 (GND), U302.1 (GND), U302.17 (GND), U303.5 (GND), U303.9 (GND), U304.10 (Vee), U304.11 (Vee), U305.1 (GND), U305.3 (GND), X301.2 (GND); also elsewhere on the board
unnamed: C308.1, L301.2, R314.1
unnamed: C309.1, R314.2, R315.1, TP302.1, U304.7 (~CLK2)
unnamed: C312.1, U303.4 (VBB)
unnamed: C319.1, R306.1, X301.3 (OUT)
unnamed: R301.1, U301.1 (Vtp)
unnamed: R302.1, U301.4 (Vtn)
unnamed: R303.2, U301.6 (~LE)
unnamed: R304.2, U301.14 (HYS)
unnamed: R305.2, U301.7 (LE)
unnamed: R306.2, U302.6 (INP0)
unnamed: R309.1, R310.2, U301.10 (~Q), U304.9 (~CLK3)
unnamed: R311.1, R312.2, U301.11 (Q), U304.8 (CLK3)
unnamed: R313.2, U304.5 (~CLK1)
unnamed: R316.1, R319.2, U302.11 (OUTP1), U304.2 (CLK0)
unnamed: R317.1, R320.2, U302.12 (OUTN1), U304.3 (~CLK0)
unnamed: R318.2, U304.4 (CLK1)
unnamed: R321.2, R323.2, U302.9 (OUTP0), U303.2 (IN)
unnamed: R322.1, R325.2, U302.10 (OUTN0), U303.3 (~IN)
unnamed: R324.1, U303.7 (Q)
unnamed: TP303.1, U304.13 (Vbb1)
unnamed: TP304.1, U304.12 (Vbb2)
unnamed: TP305.1, U302.13 (OUTP2)
unnamed: TP306.1, U302.14 (OUTN2)
unnamed: U304.15 (nQ), U305.6 (RF1_IO1)
unnamed: U304.16 (Q), U305.5 (RF2_IO1)

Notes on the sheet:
6 mA
170 mA
LVPECL OUTPUT
EXT ANALOG TRIG
LVPECL TERMINATION
+/- 2V
EXT TRIG PULSE
50 ohm input impedance
LVCMOS
Vbb NOT USED WITH LVPECL
TRIGGER SOURCE SELECT MUX 0 - 10 MHZ CLK 1 - UNUSED 2 - ANALOG TRIGGER 3 - EXT PULSE
EXT FPGA CLOCK BUFFER
UNUSED OUTPUTS CAN BE LEFT FLOATING
CROSSOVER TRIGGER SIGNAL FOR LAYOUT REASONS...

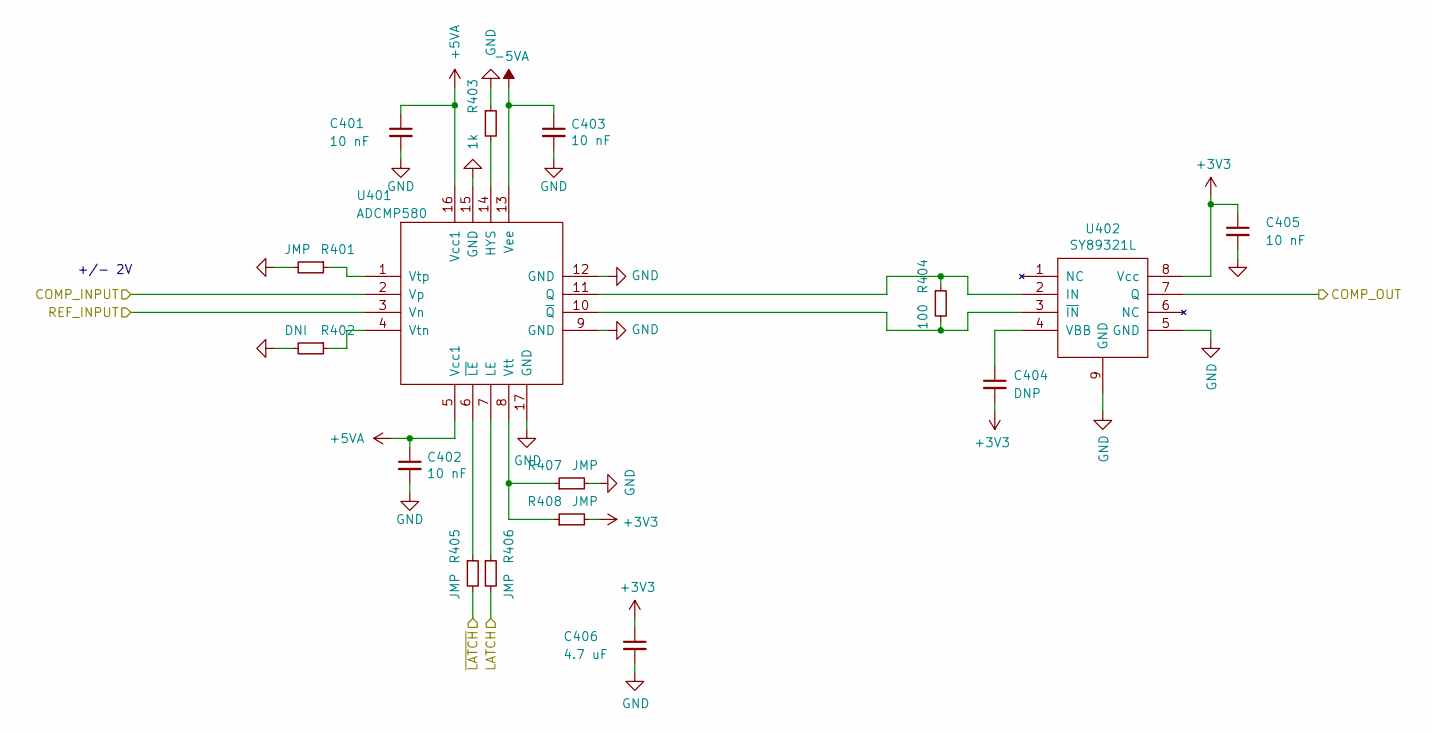
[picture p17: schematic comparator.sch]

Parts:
C401, C402, C403, C405: 10 nF; C_0402
C404: DNP; C_0402
C406: 4.7 uF; C_0603
R401, R405, R406, R407, R408: JMP; R_0402
R402: DNI; R_0402
R403: 1k; R_0402
R404: 100; R_0402
U401: ADCMP580; QFN-16-1EP_3x3mm_Pitch0.5mm
U402: SY89321L; DFN-8-1EP_2x2mm_Pitch0.5mm

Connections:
+3V3: C404.2, C405.1, C406.1, R408.2, U402.8 (Vcc); also elsewhere on the board
+5VA: C401.1, C402.1, U401.5 (Vcc1), U401.16 (Vcc1); also elsewhere on the board
-5VA: C403.1, U401.13 (Vee); also elsewhere on the board
/COMPARATOR_OUTPUT: U402.7 (Q); also elsewhere on the board
/LATCH: R406.2; also elsewhere on the board
/conn_power/ANALOG_INPUT: U401.2 (Vp); also elsewhere on the board
/sheet5C262FB0/DAC_VOUT: U401.3 (Vn); also elsewhere on the board
/~LATCH: R405.2; also elsewhere on the board
GND: C401.2, C402.2, C403.2, C405.2, C406.2, R401.2, R402.2, R403.1, R407.2, U401.9 (GND), U401.12 (GND), U401.15 (GND), U401.17 (GND), U402.5 (GND), U402.9 (GND); also elsewhere on the board
unnamed: C404.1, U402.4 (VBB)
unnamed: R401.1, U401.1 (Vtp)
unnamed: R402.1, U401.4 (Vtn)
unnamed: R403.2, U401.14 (HYS)
unnamed: R404.1, U401.11 (Q), U402.2 (IN)
unnamed: R404.2, U401.10 (~Q), U402.3 (~IN)
unnamed: R405.1, U401.6 (~LE)
unnamed: R406.1, U401.7 (LE)
unnamed: R407.1, R408.1, U401.8 (Vtt)

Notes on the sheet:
+/- 2V

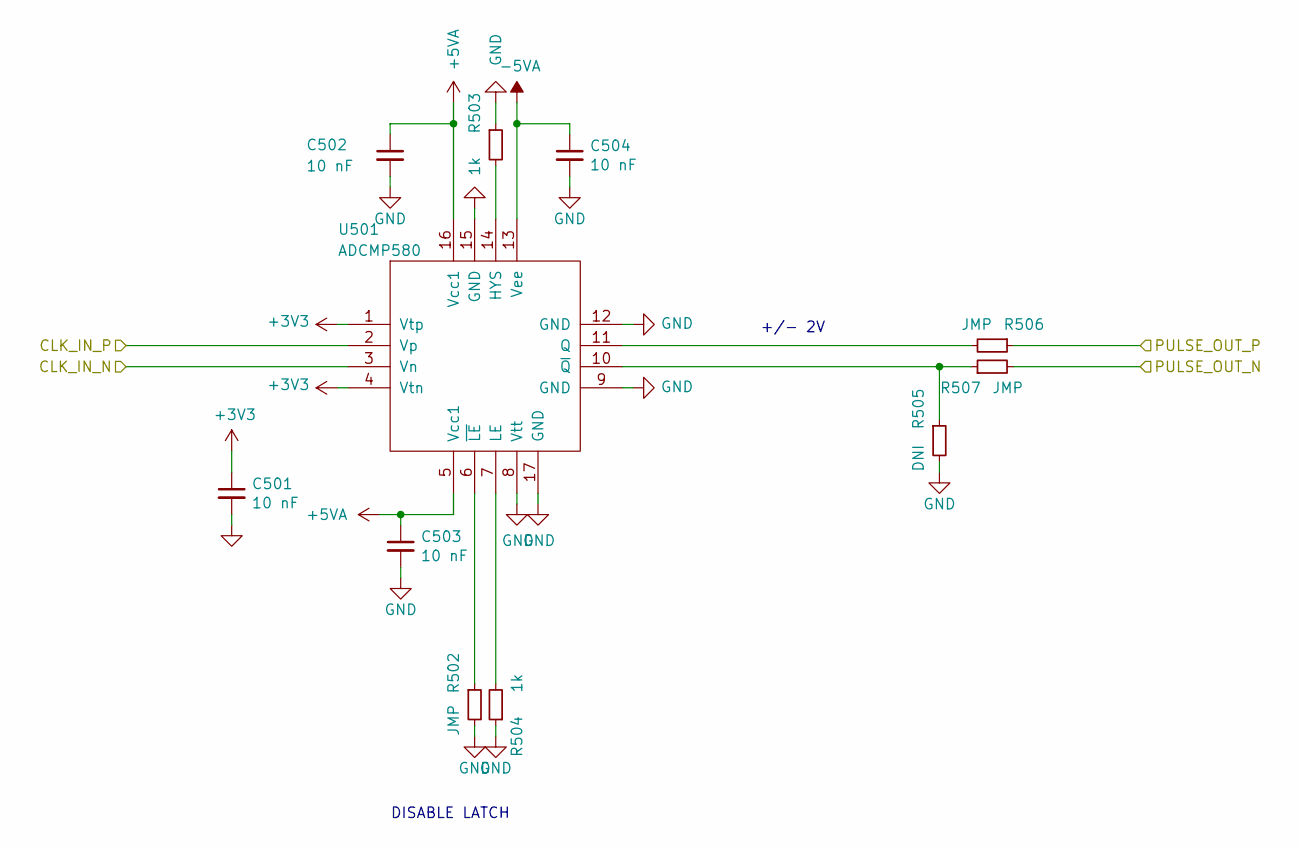
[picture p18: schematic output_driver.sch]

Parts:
C501, C502, C503, C504: 10 nF; C_0402
R502: JMP; R_0402
R503, R504: 1k; R_0402
R505: DNI; R_0402
R506, R507: JMP; R_0201
U501: ADCMP580; QFN-16-1EP_3x3mm_Pitch0.5mm

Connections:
+3V3: C501.1, U501.1 (Vtp), U501.4 (Vtn); also elsewhere on the board
+5VA: C502.1, C503.1, U501.5 (Vcc1), U501.16 (Vcc1); also elsewhere on the board
-5VA: C504.1, U501.13 (Vee); also elsewhere on the board
/conn_power/PULSE_OUT_N: R507.2; also elsewhere on the board
/conn_power/PULSE_OUT_P: R506.1; also elsewhere on the board
/output_driver/CLK_IN_N: U501.3 (Vn); also elsewhere on the board
/output_driver/CLK_IN_P: U501.2 (Vp); also elsewhere on the board
GND: C501.2, C502.2, C503.2, C504.2, R502.2, R503.1, R504.1, R505.2, U501.8 (Vtt), U501.9 (GND), U501.12 (GND), U501.15 (GND), U501.17 (GND); also elsewhere on the board
unnamed: R502.1, U501.6 (~LE)
unnamed: R503.2, U501.14 (HYS)
unnamed: R504.2, U501.7 (LE)
unnamed: R505.1, R507.1, U501.10 (~Q)
unnamed: R506.2, U501.11 (Q)

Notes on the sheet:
+/- 2V
DISABLE LATCH

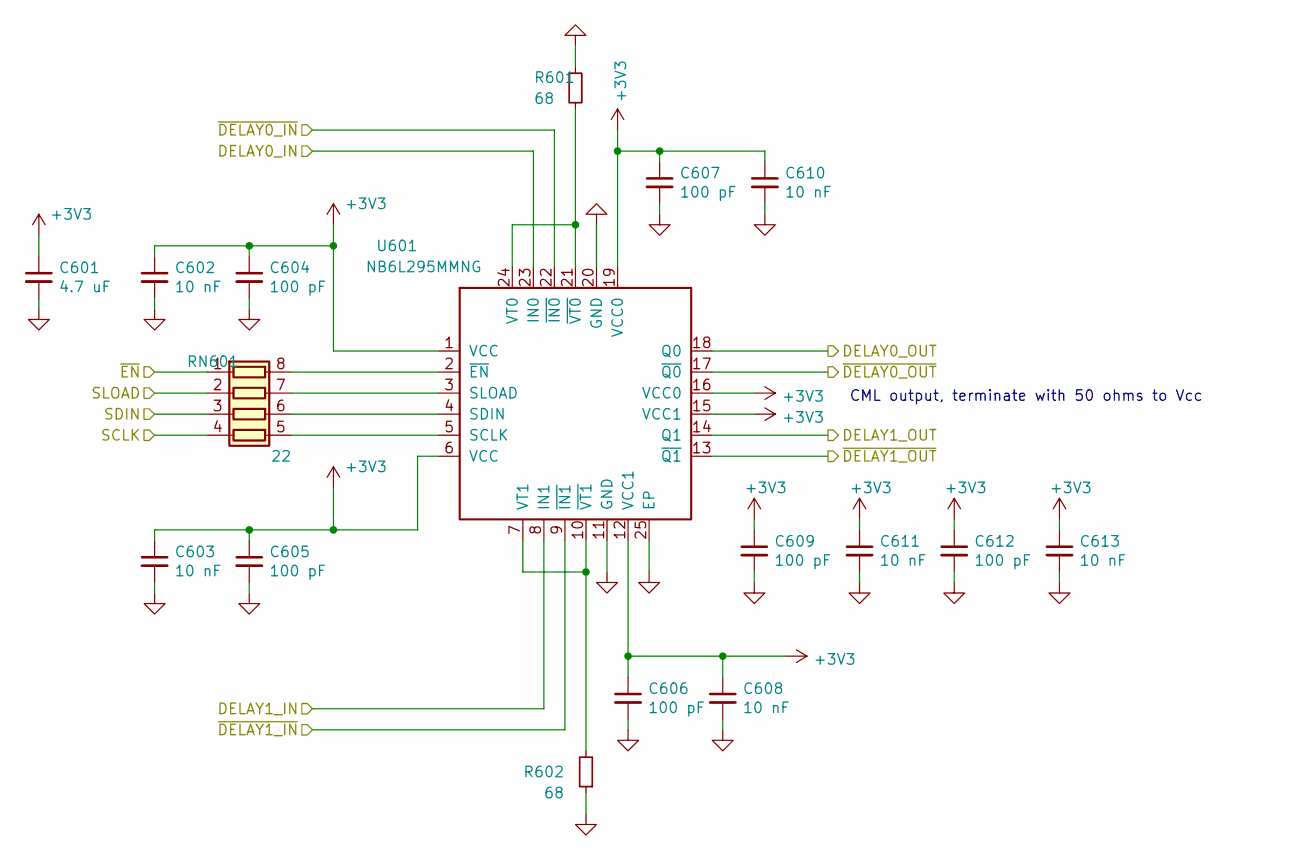
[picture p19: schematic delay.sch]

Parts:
C601: 4.7 uF; C_0603
C602, C603, C608, C610, C611, C613: 10 nF; C_0402
C604, C605, C606, C607, C609, C612: 100 pF; C_0402
R601, R602: 68; R_0402
RN601: 22; R_Array_Convex_4x0402
U601: NB6L295MMNG; QFN-24-1EP_4x4mm_Pitch0.5mm

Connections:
+3V3: C601.1, C602.1, C603.1, C604.1, C605.1, C606.1, C607.1, C608.1, C609.1, C610.1, C611.1, C612.1, C613.1, U601.1 (VCC), U601.6 (VCC), U601.12 (VCC1), U601.15 (VCC1), U601.16 (VCC0), U601.19 (VCC0); also elsewhere on the board
/CLK_PULSE_N: U601.22 (~IN0); also elsewhere on the board
/CLK_PULSE_P: U601.23 (IN0); also elsewhere on the board
/CLK_SAMPLE_N: U601.8 (IN1); also elsewhere on the board
/CLK_SAMPLE_P: U601.9 (~IN1); also elsewhere on the board
/LATCH: U601.13 (~Q1); also elsewhere on the board
/fpga_connector/DELAY_SCLK: RN601.4 (R4.1); also elsewhere on the board
/fpga_connector/DELAY_SDIN: RN601.3 (R3.1); also elsewhere on the board
/fpga_connector/DELAY_SLOAD: RN601.2 (R2.1); also elsewhere on the board
/fpga_connector/DELAY_~EN: RN601.1 (R1.1); also elsewhere on the board
/output_driver/CLK_IN_N: U601.17 (~Q0); also elsewhere on the board
/output_driver/CLK_IN_P: U601.18 (Q0); also elsewhere on the board
/~LATCH: U601.14 (Q1); also elsewhere on the board
GND: C601.2, C602.2, C603.2, C604.2, C605.2, C606.2, C607.2, C608.2, C609.2, C610.2, C611.2, C612.2, C613.2, R601.1, R602.1, U601.11 (GND), U601.20 (GND), U601.25 (EP); also elsewhere on the board
unnamed: R601.2, U601.21 (~VT0), U601.24 (VT0)
unnamed: R602.2, U601.7 (VT1), U601.10 (~VT1)
unnamed: RN601.5 (R4.2), U601.5 (SCLK)
unnamed: RN601.6 (R3.2), U601.4 (SDIN)
unnamed: RN601.7 (R2.2), U601.3 (SLOAD)
unnamed: RN601.8 (R1.2), U601.2 (~EN)

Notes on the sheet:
CML output, terminate with 50 ohms to Vcc

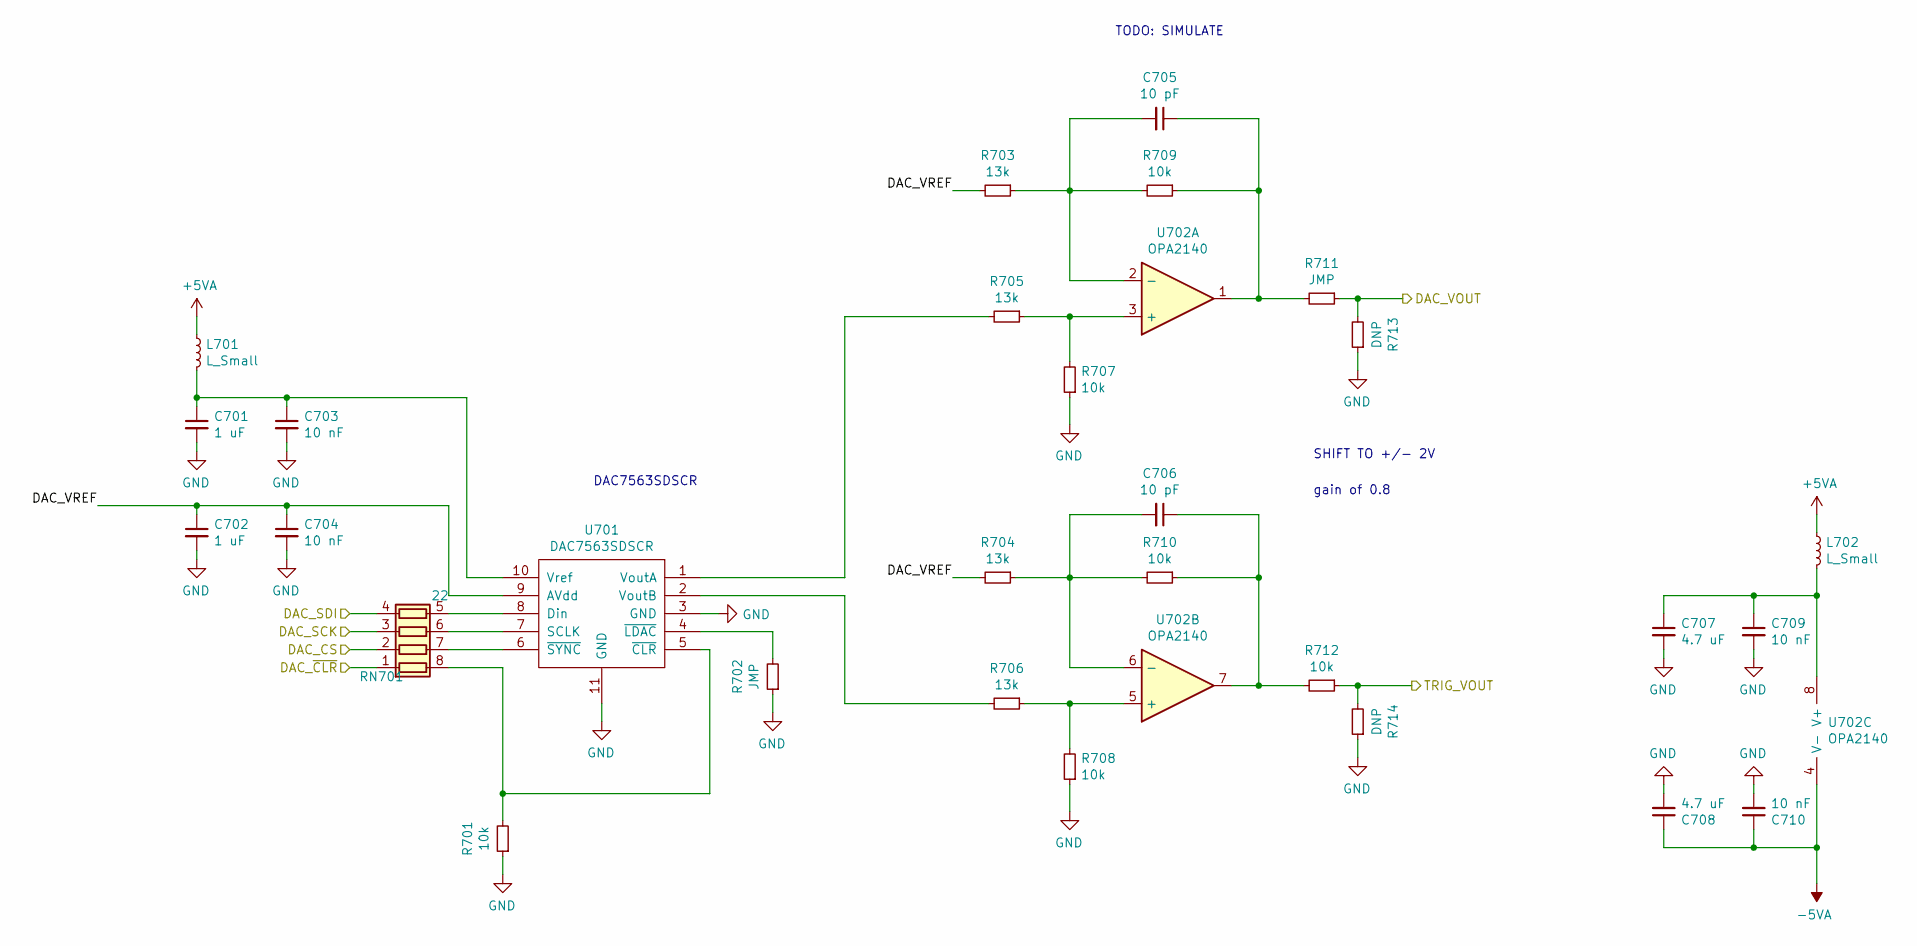
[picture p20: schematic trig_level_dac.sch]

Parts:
C701, C702: 1 uF; C_0402
C703, C704, C709, C710: 10 nF; C_0402
C705, C706: 10 pF; C_0402
C707, C708: 4.7 uF; C_0603
L701, L702: L_Small; R_0402
R701, R707, R708, R709, R710, R712: 10k; R_0402
R702, R711: JMP; R_0402
R703, R704, R705, R706: 13k; R_0402
R713, R714: DNP; R_0402
RN701: 22; R_Array_Convex_4x0402
U701: DAC7563SDSCR; DFN-10-1EP_3x3mm_Pitch0.5mm
U702: OPA2140; MSOP-8_3x3mm_Pitch0.65mm

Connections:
+5VA: L701.1, L702.1; also elsewhere on the board
-5VA: C708.1, C710.1, U702.4 (V-); also elsewhere on the board
/ANALOG_TRIG_LEVEL: R712.1, R714.2; also elsewhere on the board
/fpga_connector/DAC_CS: RN701.2 (R2.1); also elsewhere on the board
/fpga_connector/DAC_SCK: RN701.3 (R3.1); also elsewhere on the board
/fpga_connector/DAC_SDI: RN701.4 (R4.1); also elsewhere on the board
/fpga_connector/DAC_~CLR: RN701.1 (R1.1); also elsewhere on the board
/sheet5C262FB0/DAC_VOUT: R711.1, R713.2; also elsewhere on the board
/sheet5C262FB0/DAC_VREF: C702.1, C704.1, R703.2, R704.2, U701.9 (AVdd)
GND: C701.2, C702.2, C703.2, C704.2, C707.2, C708.2, C709.2, C710.2, R701.1, R702.1, R707.1, R708.1, R713.1, R714.1, U701.3 (GND), U701.11 (GND); also elsewhere on the board
unnamed: C701.1, C703.1, L701.2, U701.10 (Vref)
unnamed: C705.1, R709.1, R711.2, U702.1
unnamed: C705.2, R703.1, R709.2, U702.2 (-)
unnamed: C706.1, R710.1, R712.2, U702.7
unnamed: C706.2, R704.1, R710.2, U702.6 (-)
unnamed: C707.1, C709.1, L702.2, U702.8 (V+)
unnamed: R701.2, RN701.8 (R1.2), U701.5 (~CLR)
unnamed: R702.2, U701.4 (~LDAC)
unnamed: R705.1, R707.2, U702.3 (+)
unnamed: R705.2, U701.1 (VoutA)
unnamed: R706.1, R708.2, U702.5 (+)
unnamed: R706.2, U701.2 (VoutB)
unnamed: RN701.5 (R4.2), U701.8 (Din)
unnamed: RN701.6 (R3.2), U701.7 (SCLK)
unnamed: RN701.7 (R2.2), U701.6 (~SYNC)

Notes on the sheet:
DAC7563SDSCR
SHIFT TO +/- 2V
gain of 0.8
TODO: SIMULATE

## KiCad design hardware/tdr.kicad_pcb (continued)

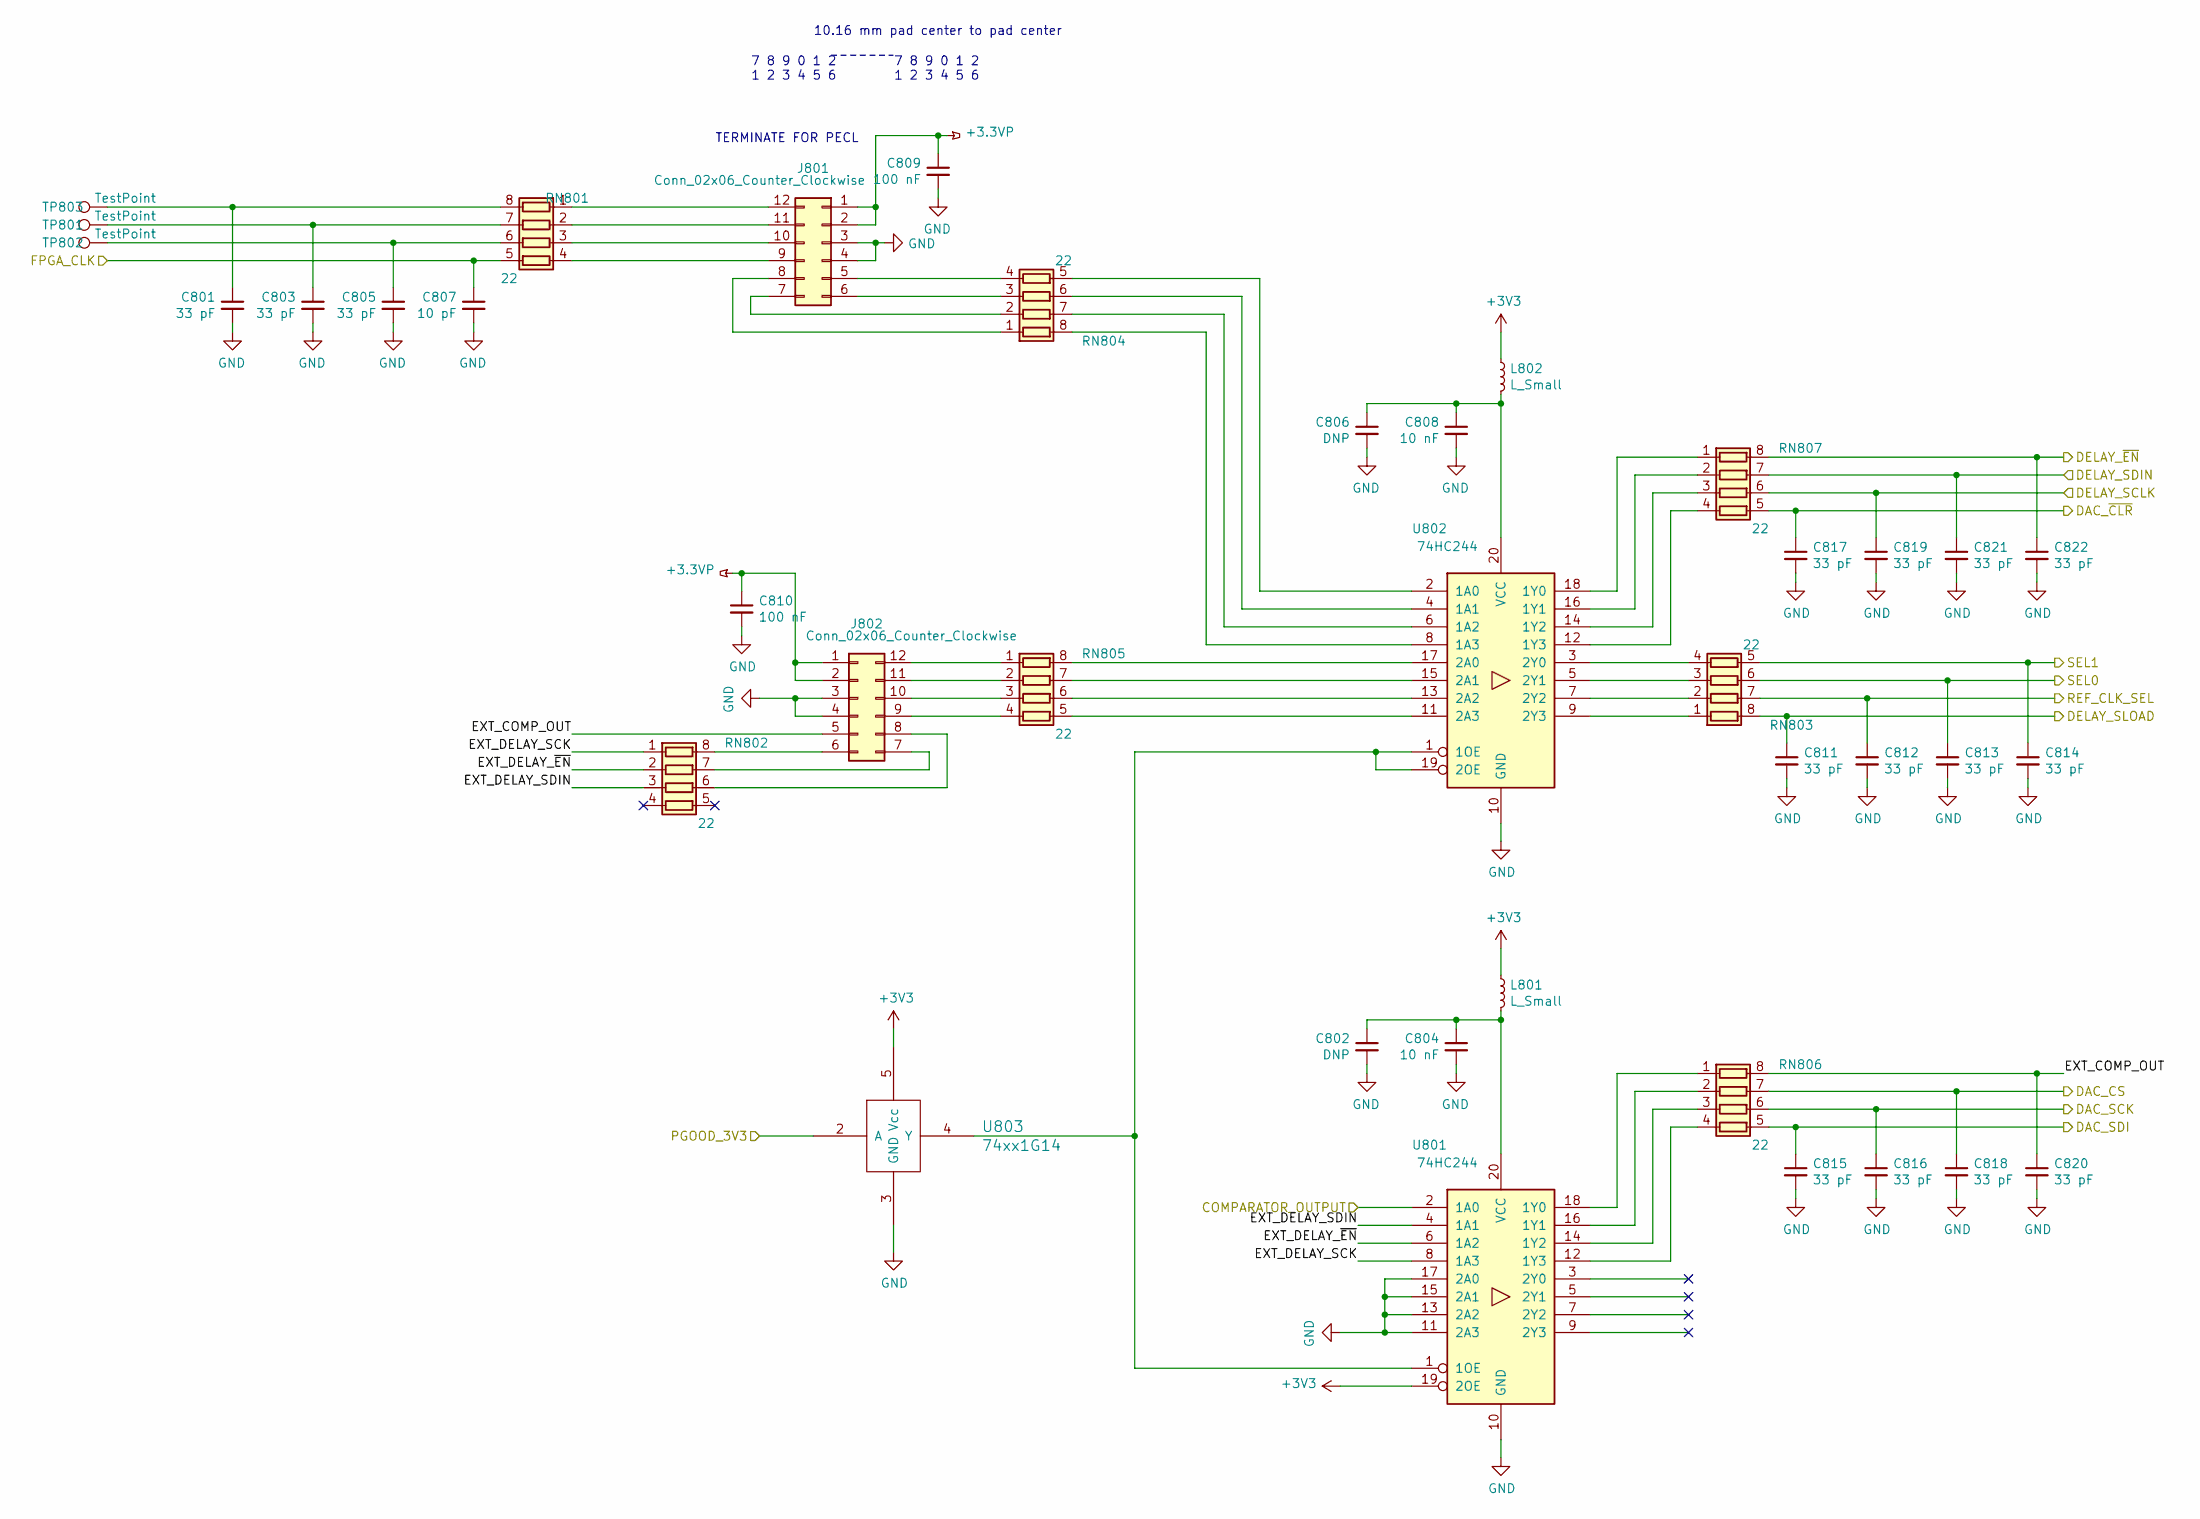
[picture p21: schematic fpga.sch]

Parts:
C801, C803, C805, C811, C812, C813, C814, C815, C816, C817, C818, C819, C820, C821, C822: 33 pF; C_0402
C802, C806: DNP; C_0603
C804, C808: 10 nF; C_0402
C807: 10 pF; C_0402
C809, C810: 100 nF; C_0402
J801, J802: Conn_02x06_Counter_Clockwise; Pin_Header_Angled_2x06
L801, L802: L_Small; R_0402
RN801, RN802, RN803, RN804, RN805, RN806, RN807: 22; R_Array_Convex_4x0402
TP801, TP802, TP803: TestPoint; TP07R
U801, U802: 74HC244; TSSOP-20_4.4x6.5mm_Pitch0.65mm
U803: 74xx1G14; SOT-23-5

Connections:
+3.3VP: C809.1, C810.1, J801.1, J801.2, J802.1, J802.2
+3V3: L801.1, L802.1, U801.19 (2OE), U803.5 (Vcc); also elsewhere on the board
/COMPARATOR_OUTPUT: U801.2 (1A0); also elsewhere on the board
/PGOOD_3V3: U803.2 (A); also elsewhere on the board
/clock/CLK_FPGA: C807.1, RN801.5 (R4.2); also elsewhere on the board
/clock/CLK_SEL: C812.1, RN803.7 (R2.2); also elsewhere on the board
/fpga_connector/DAC_CS: C818.1, RN806.7 (R2.2); also elsewhere on the board
/fpga_connector/DAC_SCK: C816.1, RN806.6 (R3.2); also elsewhere on the board
/fpga_connector/DAC_SDI: C815.1, RN806.5 (R4.2); also elsewhere on the board
/fpga_connector/DAC_~CLR: C817.1, RN807.5 (R4.2); also elsewhere on the board
/fpga_connector/DELAY_SCLK: C819.1, RN807.6 (R3.2); also elsewhere on the board
/fpga_connector/DELAY_SDIN: C821.1, RN807.7 (R2.2); also elsewhere on the board
/fpga_connector/DELAY_SLOAD: C811.1, RN803.8 (R1.2); also elsewhere on the board
/fpga_connector/DELAY_~EN: C822.1, RN807.8 (R1.2); also elsewhere on the board
/fpga_connector/EXT_COMP_OUT: C820.1, J802.5, RN806.8 (R1.2)
/fpga_connector/EXT_DELAY_SCK: RN802.1 (R1.1), U801.8 (1A3)
/fpga_connector/EXT_DELAY_SDIN: RN802.3 (R3.1), U801.4 (1A1)
/fpga_connector/EXT_DELAY_~EN: RN802.2 (R2.1), U801.6 (1A2)
/fpga_connector/SEL0: C813.1, RN803.6 (R3.2); also elsewhere on the board
/fpga_connector/SEL1: C814.1, RN803.5 (R4.2); also elsewhere on the board
GND: C801.2, C802.2, C803.2, C804.2, C805.2, C806.2, C807.2, C808.2, C809.2, C810.2, C811.2, C812.2, C813.2, C814.2, C815.2, C816.2, C817.2, C818.2, C819.2, C820.2, C821.2, C822.2, J801.3, J801.4, J802.3, J802.4, U801.10 (GND), U801.11 (2A3), U801.13 (2A2), U801.15 (2A1), U801.17 (2A0), U802.10 (GND), U803.3 (GND); also elsewhere on the board
unnamed: C801.1, RN801.8 (R1.2), TP803.1
unnamed: C802.1, C804.1, L801.2, U801.20 (VCC)
unnamed: C803.1, RN801.7 (R2.2), TP801.1
unnamed: C805.1, RN801.6 (R3.2), TP802.1
unnamed: C806.1, C808.1, L802.2, U802.20 (VCC)
unnamed: J801.5, RN804.4 (R4.1)
unnamed: J801.6, RN804.3 (R3.1)
unnamed: J801.7, RN804.2 (R2.1)
unnamed: J801.8, RN804.1 (R1.1)
unnamed: J801.9, RN801.4 (R4.1)
unnamed: J801.10, RN801.3 (R3.1)
unnamed: J801.11, RN801.2 (R2.1)
unnamed: J801.12, RN801.1 (R1.1)
unnamed: J802.6, RN802.8 (R1.2)
unnamed: J802.7, RN802.7 (R2.2)
unnamed: J802.8, RN802.6 (R3.2)
unnamed: J802.9, RN805.4 (R4.1)
unnamed: J802.10, RN805.3 (R3.1)
unnamed: J802.11, RN805.2 (R2.1)
unnamed: J802.12, RN805.1 (R1.1)
unnamed: RN803.1 (R1.1), U802.9 (2Y3)
unnamed: RN803.2 (R2.1), U802.7 (2Y2)
unnamed: RN803.3 (R3.1), U802.5 (2Y1)
unnamed: RN803.4 (R4.1), U802.3 (2Y0)
unnamed: RN804.5 (R4.2), U802.2 (1A0)
unnamed: RN804.6 (R3.2), U802.4 (1A1)
unnamed: RN804.7 (R2.2), U802.6 (1A2)
unnamed: RN804.8 (R1.2), U802.8 (1A3)
unnamed: RN805.5 (R4.2), U802.11 (2A3)
unnamed: RN805.6 (R3.2), U802.13 (2A2)
unnamed: RN805.7 (R2.2), U802.15 (2A1)
unnamed: RN805.8 (R1.2), U802.17 (2A0)
unnamed: RN806.1 (R1.1), U801.18 (1Y0)
unnamed: RN806.2 (R2.1), U801.16 (1Y1)
unnamed: RN806.3 (R3.1), U801.14 (1Y2)
unnamed: RN806.4 (R4.1), U801.12 (1Y3)
unnamed: RN807.1 (R1.1), U802.18 (1Y0)
unnamed: RN807.2 (R2.1), U802.16 (1Y1)
unnamed: RN807.3 (R3.1), U802.14 (1Y2)
unnamed: RN807.4 (R4.1), U802.12 (1Y3)
unnamed: U801.1 (1OE), U802.1 (1OE), U802.19 (2OE), U803.4 (Y)

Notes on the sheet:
TERMINATE FOR PECL
7 8 9 0 1 2 1 2 3 4 5 6
10.16 mm pad center to pad center

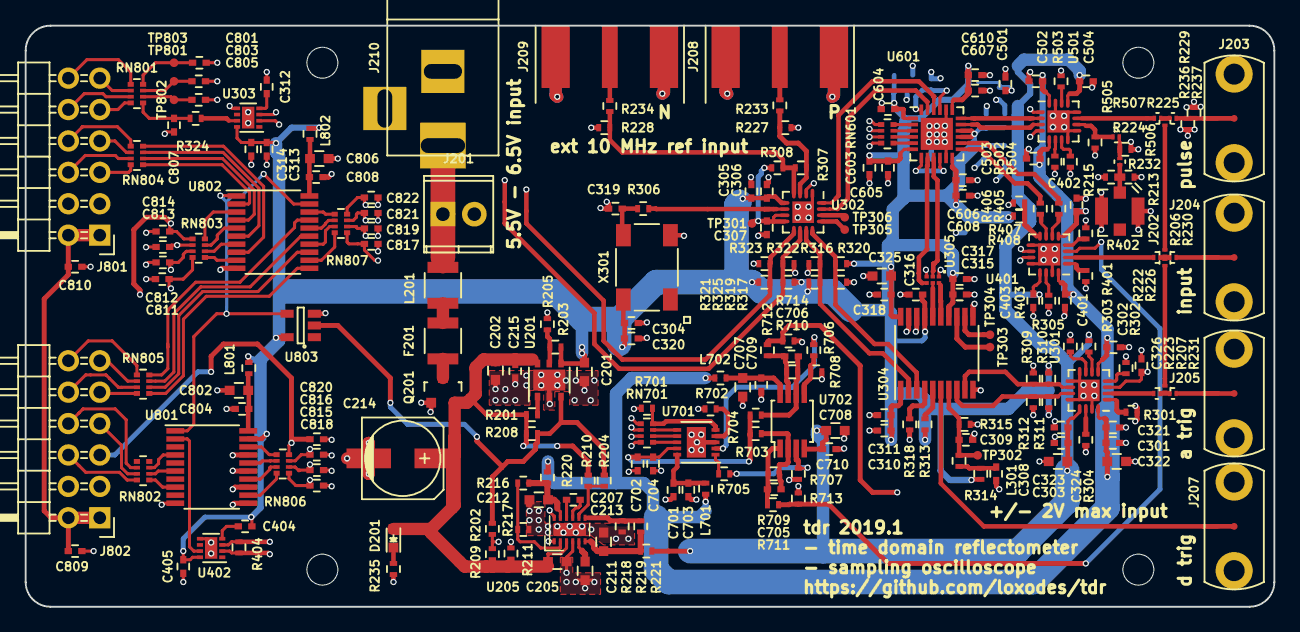
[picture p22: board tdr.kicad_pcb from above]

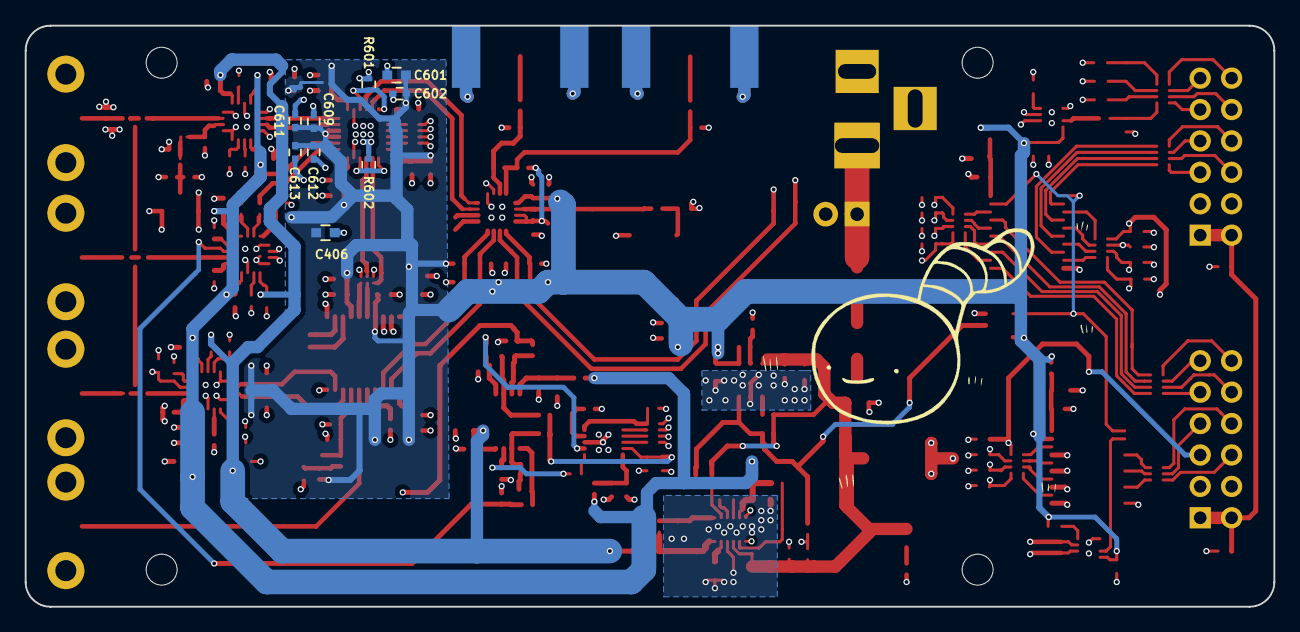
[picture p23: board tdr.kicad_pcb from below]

Board: 4 copper layers, 101.0 x 47.0 mm, 239 parts (9 on the bottom side), 170 nets.

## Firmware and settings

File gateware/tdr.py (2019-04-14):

# jon klein
# tdr gateware

# this is my first attempt at HDL in awhile and my first time using migen
# copying from this is probably a bad idea

# mit license

from migen import *
from migen.fhdl import verilog
from migen.build.platforms import ice40_up5k_b_evn
from migen.build.generic_platform import *

import pins

from spi import _SPI_TX_Master
from delay import DelayController
from uart import UartTx
from dac import DacController 



#class RefSelect(Module):
#    def __init__(self):
#        # outputs
#        self.ref_sel = Signal(1)
#        self.trig_sel = Signal(2)
#        
#        # for now, hardcode for tdr mode with internal clock
#        self.comb += [self.ref_sel.eq(0)] # TODO: verify ref sel for internal clock
#        self.comb += [self.trig_sel.eq(0)] # TODO: verify ref sel for tdr

def ref_test(dut):
    pass

def tdr_test(dut):
    # let dac initialize
    for d in range(200):
        yield 

    for analog_value in [100, 500, 900, 3100, 4000]:
        yield dut.start_sweep.eq(0)
        yield dut.start_sweep.eq(1)
        yield
        yield dut.start_sweep.eq(0)

        for d in range(7000):
            comp_val = dut.cmp_voltage < analog_value
            yield dut.comp_in.eq(comp_val)
            yield

class TDRController(Module):
    def __init__(self, plat = None):
        simulation = (plat == None)
         
        DELAY_STEPS = 500 
        DAC_SETTLE_CYCLES = int((12e6) * (10e-6))
        DELAY_SETTLE_CYCLES = int((12e6) * (10e-6))

        if not simulation:
            # external inputs
            self.comp_in = plat.request("comp_in", 0)

            # external outputs
            self.start_sweep = plat.request("start_sweep", 0)

            self.delay_sck = plat.request("delay_sck", 0) 
            self.delay_en = plat.request("delay_en", 0)
            self.delay_sdin = plat.request("delay_sdin", 0)
            self.delay_sload = plat.request("delay_sload", 0)

            self.trig_sel0 = plat.request("trig_sel0", 0)
            self.trig_sel1 = plat.request("trig_sel1", 0)
            self.ref_sel = plat.request("ref_sel", 0)

            self.dac_clr = plat.request("dac_clr", 0)
            self.dac_cs =  plat.request("dac_cs", 0)
            self.dac_sck = plat.request("dac_sck", 0)
            self.dac_sdi = plat.request("dac_sdi", 0)


            self.uart_tx =  plat.request("uart_tx", 0)
            self.uart_rx =  plat.request("uart_rx", 0)
            
            self.clk_in =  plat.request("clk_in", 0)
            self.clk_out = plat.request("clk_out", 0)


        else:
            # external inputs
            self.comp_in = Signal()
            self.start_sweep = Signal()

            # external outputs
            self.delay_sck = Signal()
            self.delay_en = Signal()
            self.delay_sdin = Signal()
            self.delay_sload = Signal()

            self.trig_sel0 = Signal()
            self.trig_sel1 = Signal()
            self.ref_sel = Signal()

            self.dac_clr = Signal()
            self.dac_cs = Signal()
            self.dac_sck = Signal() 
            self.dac_sdi = Signal()

            self.uart_tx = Signal()
            self.uart_rx = Signal()

            self.clk_in = Signal()
            self.clk_out = Signal()


            DELAY_STEPS = 3


        # internal signals
        delay_state = Signal(11)
        self.cmp_voltage = cmp_voltage = Signal(12)
        cmp_bit = Signal(5)
        settle_count = Signal(16)

        # ...
        self.comb += self.clk_out.eq(self.clk_in)

        # create dac controller
        dac_controller = DacController()
        self.submodules += dac_controller
        self.comb += [
            self.dac_clr.eq(dac_controller.dac_clr),
            self.dac_cs.eq(dac_controller.dac_cs),
            self.dac_sck.eq(dac_controller.dac_sck),
            self.dac_sdi.eq(dac_controller.dac_sdi)]
        
        # create delay controller
        delay_controller = DelayController()
        self.submodules += delay_controller
        self.comb += [
            self.delay_sck.eq(delay_controller.sck),
            self.delay_en.eq(delay_controller.en),
            self.delay_sdin.eq(delay_controller.sdin),
            self.delay_sload.eq(delay_controller.sload)]

        self.comb += delay_controller.delay2.eq(delay_state)
        self.comb += delay_controller.delay1.eq(0)

        # create ref select, assign to external pins
        #ref_select = RefSelect()
        #self.submodules += ref_select
        self.comb += [
            self.ref_sel.eq(0),
            self.trig_sel0.eq(0),
            self.trig_sel1.eq(0)]

        # create uart tx
        uart_tx = UartTx(sim = simulation)
        self.submodules += uart_tx
        self.comb += [self.uart_tx.eq(uart_tx.tx)]

        # create fsm
        tdrfsm = FSM(reset_state="INIT")
        self.submodules += tdrfsm

        # INIT - wait for DAC to become ready
        tdrfsm.act("INIT",
            If(dac_controller.ready,
                NextState("WAIT_FOR_SWEEP"),
            ),
        )

        tdrfsm.act("WAIT_FOR_SWEEP",
            self.start_sweep.eq(1),
            #NextState("START_SWEEP"),
            If(self.uart_rx == 0,
                NextState("START_SWEEP"),
            ),
        )

        tdrfsm.act("START_SWEEP",
            NextState("SET_DELAY"),
            NextValue(delay_state, 0),
            NextValue(cmp_voltage, 2048),
            #NextValue(cmp_voltage, 0),
            NextValue(cmp_bit, 10)

        )


        tdrfsm.act("SET_DELAY",
            # PROGRAM DELAY LINES 
            NextState("WAIT_FOR_DELAY"),
            delay_controller.load.eq(1),
            NextValue(settle_count, DELAY_SETTLE_CYCLES),
        )

        tdrfsm.act("WAIT_FOR_DELAY",
            # WAIT FOR DELAY LINES TO FINISH
            NextValue(settle_count, settle_count - 1),
            If(delay_controller.ready & (settle_count == 0),
                NextState("SET_VOLTAGE"),
            ),
        )
    
        tdrfsm.act("SET_VOLTAGE",
            # SET VOLTAGE TO CMP_VOLTAGE
            dac_controller.dac_a.eq(0),
            dac_controller.dac_b.eq(cmp_voltage),
            dac_controller.load.eq(1),
            NextState("WAIT_FOR_VOLTAGE"),

        )

        tdrfsm.act("WAIT_FOR_VOLTAGE",
            If(dac_controller.ready,
                NextState("SETTLE_VOLTAGE"),
                NextValue(settle_count, DAC_SETTLE_CYCLES),
            ),
        )


        tdrfsm.act("SETTLE_VOLTAGE",
            If(settle_count == 0,
                NextState("MEASURE_VOLTAGE_BINARY"),
            ),
            NextValue(settle_count, settle_count - 1), 
        )

        tdrfsm.act("MEASURE_VOLTAGE_BINARY",
            If(self.comp_in,
                NextValue(cmp_voltage, cmp_voltage + (1 << cmp_bit))
            ).Else(
                NextValue(cmp_voltage, cmp_voltage - (1 << cmp_bit))
                
            ),


            NextValue(cmp_bit, cmp_bit -1),

            If(cmp_bit == 0,
                NextState("SEND_VOLTAGE_LSB"),
            ).Else(
                NextState("SET_VOLTAGE"),
            ),
        )


        tdrfsm.act("MEASURE_VOLTAGE_BRUTE",
            If((self.comp_in == 0) | (cmp_voltage > 3800),
                NextState("SEND_VOLTAGE_LSB"),
                #NextValue(settle_count, 1000),
            ).Else(
                NextValue(cmp_voltage, cmp_voltage + 16),
                NextState("SET_VOLTAGE"),
            )
        )

        tdrfsm.act("SEND_VOLTAGE_LSB",
            If(uart_tx.ready,
                # send delay/voltage over uart
                uart_tx.load.eq(1),

                If(delay_state == DELAY_STEPS,
                    uart_tx.data.eq(1),
                ).Else(
                    uart_tx.data.eq(cmp_voltage & 0xFF),
                    #uart_tx.data.eq(delay_state & 0xFF),
                ),
            
                NextState("SEND_VOLTAGE_MSB"),
            )
        )

        tdrfsm.act("SEND_VOLTAGE_MSB",
            If(uart_tx.ready,
                # send delay/voltage over uart
                uart_tx.load.eq(1),

                If(delay_state == DELAY_STEPS,
                    uart_tx.data.eq(1),
                ).Else(
                    uart_tx.data.eq(cmp_voltage[8:]),
                ),
            
                If(delay_state == DELAY_STEPS,
                    NextState("WAIT_FOR_SWEEP"),
                    # if this is the sample in the sweep, return to wait for sweep
                ).Else(
                    NextState("SET_DELAY"),
                    NextValue(delay_state, delay_state + 1),
                    NextValue(cmp_voltage, 2048),
                    #NextValue(cmp_voltage, 0),
                    NextValue(cmp_bit, 10),
                    # otherwise, increment delay counter, reprogram delay
                )
            )

        )


    

if __name__ == '__main__':

    #tdr_dut = TDRController()
    #run_simulation(tdr_dut, tdr_test(tdr_dut), vcd_name="tdr.vcd")
    #verilog.convert(TDRController()).write("tdr.v")
   
    plat = ice40_up5k_b_evn.Platform()
    plat.add_extension([
        ("comp_in", 0, Pins("J3:14")),
        ("start_sweep", 0, Pins("J3:0")),
        ("delay_sck", 0, Pins("J3:1")),
        ("delay_en", 0, Pins("J3:2")),
        ("delay_sdin", 0, Pins("J3:3")),
        ("delay_sload", 0, Pins("J3:4")),
        ("trig_sel0", 0, Pins("J3:5")),
        ("trig_sel1", 0, Pins("J3:6")),
        ("ref_sel", 0, Pins("J3:7")),
        ("dac_clr", 0, Pins("J3:9")),
        ("dac_cs", 0, Pins("J3:10")),
        ("dac_sck", 0, Pins("J3:11")),
        ("dac_sdi", 0, Pins("J3:12")),
        ("uart_tx", 0, Pins("J3:13")),
        ("uart_rx", 0, Pins("J3:15")),
        ("clk_in", 0, Pins("J3:16")),
        ("clk_out", 0, Pins("J3:17")),

    ])

    plat.build(TDRController(plat = plat))
    plat.create_programmer().flash(0, 'build/top.bin')

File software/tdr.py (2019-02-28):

import time
import pdb
from mmap_gpio import GPIO
from bbone_spi_bitbang import bitbang_spi
from pylab import *

TRIG_SEL0 = (1, 6) # P8_3
TRIG_SEL1 = (1, 7) # P8_4
REF_SEL = (1, 2) # P8_5

COMP_OUT = (1, 3) # P8_6
REFCLK = (2, 2)  # P8_7

DAC_CS = (2, 3) # P8_8
DAC_SDI = (2, 5) # P8_9
DAC_SCK = (2, 4) # P8_10
DAC_CLR = (1, 13) # P8_11

DELAY_EN = (1, 12) # P8_12
DELAY_SDIN = (0, 23) # P8_13
DELAY_SCK = (0, 26) # P8_14
DELAY_SLOAD = (1, 15) # P8_15


class Dac():
    # DAC756x
    # http://www.ti.com/lit/ds/symlink/dac7563.pdf 
    # dac a is compare voltage
    # dac b is analog trigger voltage
    def __init__(self, gpio):
        self.gpio = gpio
        # msb first, data read on falling edge of clock
        # sync high at least one cycle, then low for entire transactiion
        self.spi = bitbang_spi(DAC_CS, DAC_SDI, None, DAC_SCK, rising_data = False)
        gpio.set_output(DAC_CLR)

        self.dac_cmd(0x07, 0, 1) # enable internal reference


    def dac_cmd(self, command, addr, data):
        command = ((command & 0x7) << 19) + ((addr & 0x07) << 16) + (data & 0xffff)
        self.spi.transfer(command, bits = 24)

    def set_a(self, value):
        self.dac_cmd(3, 0, value << 4)

    def set_b(self, value):
        self.dac_cmd(3, 1, value << 4)


class Delay():
    # https://www.onsemi.com/pub/Collateral/NB6L295M-D.PDF
    # delay a is pulse offset
    # delay b is trigger offset
    def __init__(self, gpio):
        self.gpio = gpio
        # lsb first, data read on rising edge of clock, en high during entire transaction
        # pulse sload on last bit after rising edge
        self.spi = bitbang_spi(DELAY_EN, DELAY_SDIN, None, DELAY_SCK, latch = DELAY_SLOAD, enable_low = False)
    
    # the chip expects lsb first, and the spi driver is msb firsr
    def _revbits(self, x, nbits = 11):
        return int(bin(x)[2:].zfill(nbits)[::-1], 2)
   
    def set_a(self, value):
        command = ((value & 0x1FF) << 2)
        command = self._revbits(command) 
        self.spi.transfer(command, bits = 11)

    def set_b(self, value):
        command = (((value & 0x1FF)) << 2) + 1
        command = self._revbits(command) 
        self.spi.transfer(command, bits = 11)


if __name__ == '__main__':
    gpio = GPIO()

    gpio.set_output(TRIG_SEL0)
    gpio.set_output(TRIG_SEL1)
    gpio.set_output(REF_SEL)

    gpio.set_input(COMP_OUT)
    gpio.set_input(REFCLK)

    delay = Delay(gpio)
    dac = Dac(gpio)
   
    NDELAYS = 1 << 9
    NDACS = 1 << 12
    
    BRUTE_FORCE_TRIG = False

    # trigger sources:
    # 0 - clk (delayed)
    # 1 - unused
    # 2 - analog trigger
    # 3 - external pulse
    gpio.set_value(TRIG_SEL0, gpio.HIGH)
    gpio.set_value(TRIG_SEL1, gpio.HIGH)

    # reference sources:
    # 0 - internal
    # 1 - external
    gpio.set_value(REF_SEL, gpio.LOW)

    # set delay a (output pulse delay) to 0
    delay.set_a(0)
    dac.set_b(2220)

    # delay b is trigger offset
    
    sweep = np.zeros(NDELAYS)
    print("dac.set_a(x <<2)")

    for trig_offset in range(NDELAYS):
        delay.set_b(trig_offset)
        
        if BRUTE_FORCE_TRIG:
            for cmp_voltage in range(NDACS):
                dac.set_a(cmp_voltage << 3)
                if not gpio.read_value(COMP_OUT):
                    sweep[trig_offset] = cmp_voltage << 3
                    break
        else:
            # binary search trigger voltage
            cmp_voltage = NDACS / 2

            for i in range(int(log2(NDACS))-2,-1,-1):
                dac.set_a(cmp_voltage)

                if gpio.read_value(COMP_OUT):
                    cmp_voltage += 1 << i
                else:
                    cmp_voltage -= 1 << i

            sweep[trig_offset] = cmp_voltage

        print("delay {}, dac {}".format(trig_offset, sweep[trig_offset]))

    print(sweep)
    sweepfile = open("sweepfile", "w")
    np.save(sweepfile, sweep)

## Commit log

2018-11-02 inital commit of tdr project, schematic in progress
    [clock.sch, comparator.sch, conn_power.sch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]
2018-11-03 more work on tdr schematic
    [clock.sch, comparator.sch, conn_power.sch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]
2018-12-09 work on tdr schematic..
    [clock.sch, comparator.sch, conn_power.sch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]
2018-12-09 footprint assignment
    [clock.sch, comparator.sch, conn_power.sch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]
2018-12-16 work on schematic..
    [conn_power.sch, fpga.sch, tdr.kicad_pcb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]
2018-12-29 work on tdr component placement
    [clock.sch, comparator.sch, conn_power.sch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]
2018-12-31 more component placement on tdr..
    [conn_power.sch, tdr.kicad_pcb]
2018-12-31 added rf crossover for latch trigger line to help with layout
    [clock.sch, tdr.kicad_pcb, tdr.sch]
2019-01-02 finished first pass component placement and drc setup, swapped digital pins for easier routing
    [conn_power.sch, fpga.sch, tdr.kicad_pcb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]
2019-01-05 layout of low speed digital traces
    [conn_power.sch, fpga.sch, output_driver.sch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]
2019-01-05 layout of low speed analog and power sections
    [tdr.kicad_pcb]
2019-01-05 routing high speed digital
    [clock.sch, tdr.kicad_pcb]
2019-01-06 more layout.. 28 unrouted nets to go
    [clock.sch, conn_power.sch, tdr.kicad_pcb]
2019-01-06 first pass of layout complete
    [clock.sch, comparator.sch, fpga.sch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]
2019-01-06 cleanup of tdr layout
    [tdr.kicad_pcb]
2019-01-07 fixed CML termination.. ready to order?
    [clock.sch, comparator.sch, delay.sch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]
2019-01-07 schematic cleanup, BOM consolidation
    [clock.sch, comparator.sch, conn_power.sch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]
2019-01-10 added interactive BOM for manual component placement
    [tdr.kicad_pcb]
2019-01-10 clean up of interactive BOM page, waiting on PCBs
    [tdr.kicad_pcb]
2019-01-31 added picture of assembled pcb, started erratum for r0..
    [comparator.sch, tdr.sch]
2019-02-08 assigned pins for tdr beaglebone bitbang driver
    [trig_level_dac.sch]
2019-02-10 fix a bunch of software bugs..
    [bbone_spi_bitbang.py, tdr.py]
2019-02-10 improve PMOD connector pin labels in schematic..
    [fpga.sch]
2019-02-21 fixed U401 and U601 output termination, tdr works, added first sweep of output pulse to README
    [comparator.sch, trig_level_dac.sch]
2019-02-21 updated tdr picture to show bodge wires, added r0 schematic pdf export
2019-02-28 fix crossover distortion on analog triggered measurements
    [clock.sch, comparator.sch]
2019-02-28 40x speedup in scope sweep speed - binary search for voltage instead of brute force
2019-03-21 work on delay and dac drivers
2019-03-27 added pin mapping to tdr.py
2019-04-07 added startup delay before configuring dac, sped up uart
2019-04-14 fpga tdr control works... for every other sample?
2019-04-14 tdr gateware works - run fpga clock off sample clock..
2019-04-26 added impedance plot, updated schematic with errata
